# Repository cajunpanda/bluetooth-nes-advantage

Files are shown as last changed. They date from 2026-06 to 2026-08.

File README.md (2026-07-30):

# Bluetooth NES Advantage (v2)

Integrated Bluetooth for the NES Advantage (NES-026) arcade stick. It pairs directly with a
Nintendo Switch, an 8BitDo NES Retro Receiver (for a real NES), and PCs, phones, and emulators
over BLE. No case cutting and no added buttons: everything runs from the stick's own controls,
and it charges through the original cable hole.

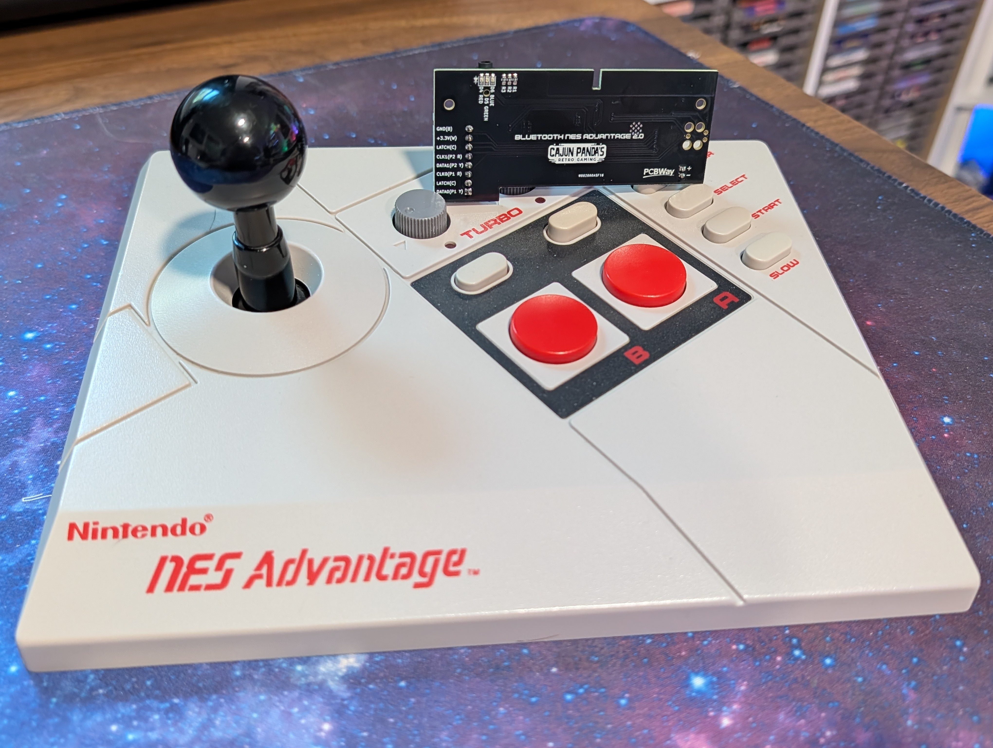
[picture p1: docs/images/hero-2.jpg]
NES Advantage with the Bluetooth board


**[Watch the overview and how-to video](https://youtu.be/xjbFiXHXB24)** for a tour of the mod and
everything below in use.

## Features

- Direct Nintendo Switch pairing (Switch Pro Controller emulation over BT Classic)
- Home, ZL + ZR (the NSO retro menu), ZL, ZR, and Capture — buttons the NES stick never had, on
  Select-held chords, instant and usable mid-game; the chord window is configurable, or off
- 8BitDo NES Retro Receiver support for playing on a real NES
- BLE gamepad mode for PC, Android, SteamOS, Linux, and BlueRetro
- Turbo and slow motion work as normal
- Player-select slider: in BLE mode the stick exposes two gamepads for take-turns play
- Wake on button press from a deep sleep that draws microamps
- Battery life on an 1800 mAh cell: about 17 hours in Switch/Receiver mode, about 37 hours in
  BLE mode, months of standby
- Low input latency: the board adds about 4 ms in Switch/Receiver mode and about 6 ms in BLE mode
- Browser-based configuration and over-the-air firmware updates, no cable needed
- RGB status LEDs, battery level monitoring, 5 V barrel jack charging
- Play while charging (load-share power path)

## Configure and update from your browser

A built-in Web Bluetooth app tests every input, tunes how the stick behaves, and flashes new
firmware over the air with no cable and nothing to install. Put the stick in config mode (hold
A + B + Select for 5 s), open the hosted
**[config page](https://cajunpanda.github.io/bluetooth-nes-advantage/)** in Chrome or Edge, and
connect. Every button, the D-pad, the player-select slider, and the turbo dials light up live as
you use them:

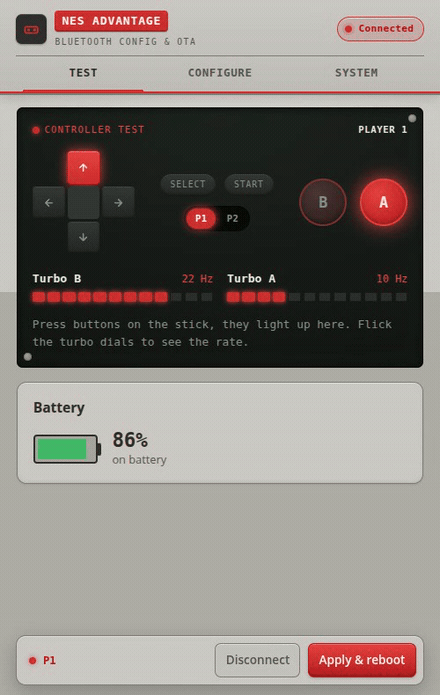
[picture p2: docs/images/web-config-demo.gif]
Live controller test in the web config page


Change transport, button profile, and directional mode and apply over the air, or drop a
`firmware.bin` on the cartridge slot to update. The
[manual](docs/MANUAL.md#configuration-and-firmware-updates) has the full walkthrough.

## How it works

A single custom PCB replaces the controller's cable. A bare ESP32-WROOM-32E reads the original
CD4021 shift registers and presents the stick as a Bluetooth gamepad in one of two modes:

- Switch mode (Bluetooth Classic): emulates a Switch Pro Controller. Pairs directly with a
  Nintendo Switch and with the 8BitDo NES Retro Receiver.
- BLE mode: a standard BLE HID gamepad ("NES Advantage") for PCs, phones, BlueRetro, and
  emulators.

Turbo, slow motion, and the player-select slider all work as originally designed.

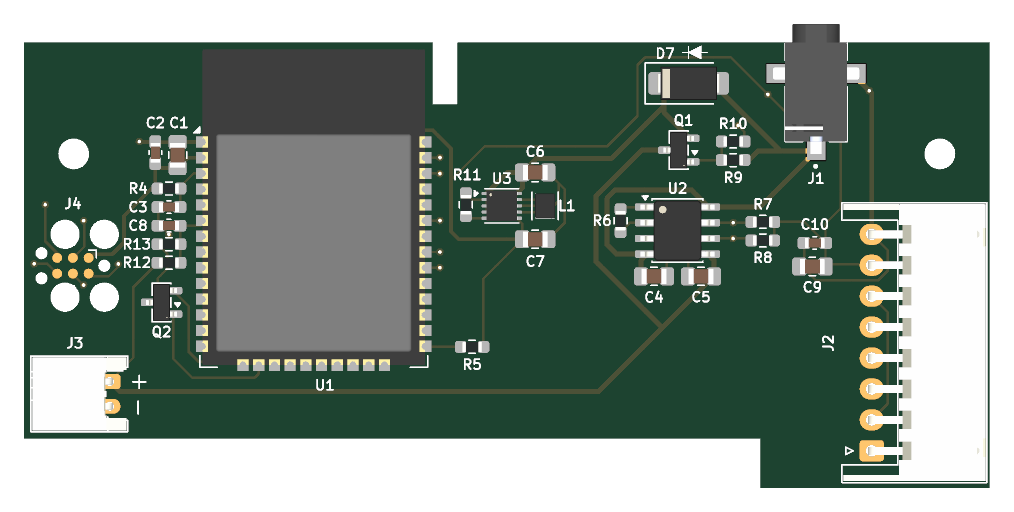
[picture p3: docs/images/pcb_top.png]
PCB top

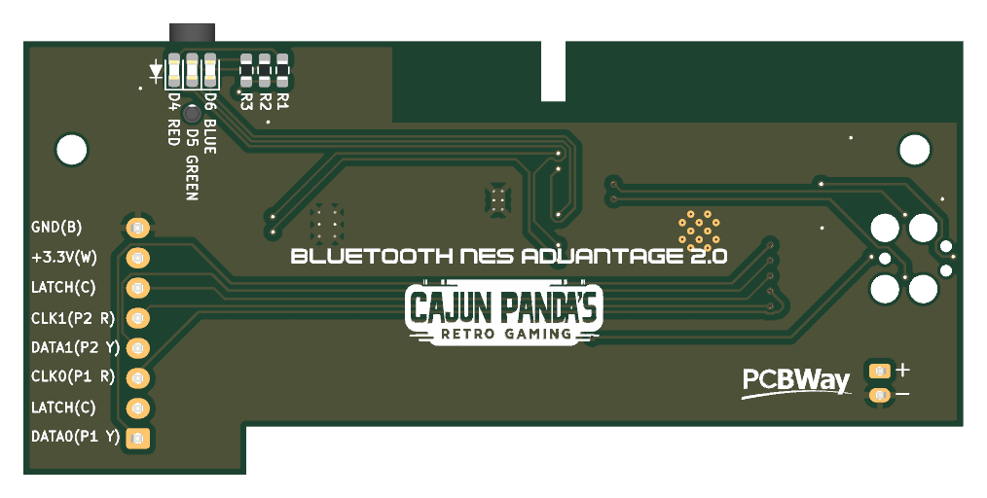
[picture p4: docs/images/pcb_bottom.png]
PCB bottom


## Documentation

Start with the guide that fits you:

- **Using a modded controller:** [docs/MANUAL.md](docs/MANUAL.md). Pairing, gestures, LEDs, button
  profiles, two-player play, charging, and firmware updates.
- **Installing the mod in your controller:** [docs/INSTALL.md](docs/INSTALL.md). Wiring the harness,
  fitting the battery and board, insulating tape, and the 3D-printed jack plug.
- **Building your own kit:** [docs/HARDWARE.md](docs/HARDWARE.md). PCB, bill of materials, board
  assembly, and connection maps.
- **Building and customizing firmware:** [docs/FIRMWARE.md](docs/FIRMWARE.md). Toolchain, module
  layout, architecture, and the config/OTA path.

## Get one prebuilt

Complete kits and assembled boards are available at
[cajunpanda.com](https://cajunpanda.com/shop/bt-nes-advantage).

## Support

Questions and help: join the [Discord](https://discord.gg/t8uT8NgTnc).

## Repository layout

| Path | Contents |
| --- | --- |
| [`firmware/`](firmware/) | ESP-IDF dual-mode Bluetooth firmware |
| [`hardware/`](hardware/) | KiCad PCB project and the 3D-printable jack plug |
| [`web/`](web/) | Web Bluetooth config and OTA update page |
| [`tools/`](tools/) | Serial monitor and build helpers |
| [`docs/`](docs/) | Manual, install guide, hardware guide, firmware guide, protocol reference |
| [`AGENTS.md`](AGENTS.md) | Working notes for contributors and AI coding agents |

## License

Licensed by medium: firmware and software under MIT, hardware (PCB and 3D models) under
CERN-OHL-P-2.0, documentation under CC-BY-4.0. See [LICENSING.md](LICENSING.md).

## PCBs

The PCBs for this product are sponsored and produced by PCBWay. As always, their service was amazing
and the fabrication as well as the shipping was fast. Because of the all-in-one customs and shipping
price, the handling of taxes and other fees was very easy.
[Click here](https://www.pcbway.com/project/shareproject/Bluetooth_NES_Advantage_865d24ef.html) to
order the PCBs from the shared project (gerbers preloaded).

## Disclaimer

This is an independent, unofficial project and is not affiliated with, endorsed by, sponsored by, or
associated with Nintendo Co., Ltd. Nintendo, NES, Nintendo Entertainment System, NES Advantage,
Nintendo Switch, and Nintendo Switch Pro Controller are trademarks of Nintendo. All trademarks are
the property of their respective owners and are used here only for identification and compatibility.
No Nintendo firmware, code, or assets are included; the Switch Pro Controller support is a clean-room
implementation of the controller's publicly documented behavior, for interoperability only.

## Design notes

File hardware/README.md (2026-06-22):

# Hardware

Open hardware for the Bluetooth NES Advantage.

| Path | Contents |
|---|---|
| [`bt-nes-advantage-pcb/`](bt-nes-advantage-pcb/) | KiCad 10 PCB project (schematic and 2-layer layout) |
| [`bt-nes-advantage-jack-plug/`](bt-nes-advantage-jack-plug/) | 3D-printable DC jack plug (STL and FreeCAD source) |

The full build reference (architecture, BOM, pin and connection maps, power path, assembly, and
layout notes) is in [`../docs/HARDWARE.md`](../docs/HARDWARE.md). Pin assignments match the firmware
(`../firmware/main/board_config.h`).

Board highlights:

- **MCU:** bare ESP32-WROOM-32E-N4 on a single 3.3 V rail (the Advantage's logic runs at 3.3 V, so
  there is no 5 V rail and no level shifting).
- **Power:** barrel jack (+5 V) to TP4056 charger, 1S LiPo, discrete load-share power path, TPS63900
  buck-boost to 3.3 V. NES LATCH/CLK/DATA sit on RTC-capable GPIOs so the ULP polls the shift
  registers in deep sleep.
- **Programming and debug:** TC2030 Tag-Connect (J4), pinned for the TC2030-FTDI-C232HD-DDHSP-0-DTR
  USB-UART cable (DTR/RTS auto-reset). No onboard USB; charging is via the barrel jack only.
- **Status:** R/G/B 0603 LEDs (active-low), visible through the transparent jack plug.
- **Board:** 2 layer, 1.6 mm, 78 x 36 mm, fits the stock case with no cutting.

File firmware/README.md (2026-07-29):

# Firmware

ESP32-WROOM-32E firmware. Native ESP-IDF v5, with two Bluetooth host stacks: BTstack for the
Classic Switch Pro Controller emulation and Bluedroid for BLE. Built with PlatformIO or plain
`idf.py`.

```bash
pio run -e wroom32 -t upload    # build and flash over the Tag-Connect cable
pio device monitor              # serial console, 115200 baud
```

The full guide (toolchain, build variants, module layout, architecture, config/OTA, and the shared
serial monitor) is in [`../docs/FIRMWARE.md`](../docs/FIRMWARE.md). The Switch Pro protocol contract
is in [`../docs/switch_pro_protocol.md`](../docs/switch_pro_protocol.md).

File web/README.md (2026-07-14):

# web: BLE configuration and OTA web app

A single-page Web Bluetooth app to test the controller, configure it, and flash new firmware
over the air. No build step, no dependencies, no external requests: one self-contained
`index.html` (inline CSS/JS). The look is a grey-and-red front-loader NES rendered as UI; see
`DESIGN.md` and `PRODUCT.md`.

## Use

1. On the controller, hold **A+B+Select for 5 s** to reboot into config/OTA mode. The
   device advertises as **"NES Advantage Config"**; the blue LED blinks while waiting and
   goes solid when connected. (On the bench you can instead enter config mode over serial
   with the `config` console command.)
2. Serve this folder from a secure context. `http://localhost` is exempt, otherwise HTTPS:
   ```bash
   cd web && python3 -m http.server 8770
   ```
   Open <http://localhost:8770/> in Chrome or Edge.
3. **Connect** and pick "NES Advantage Config". The first GATT connect on Chrome/Linux
   sometimes throws a transient `NetworkError`; the page auto-retries (a known BlueZ quirk)
   and silently reconnects if the link drops.
4. **Test:** watch every button, the D-pad, the P1/P2 select switch, and the turbo dials
   light up live, alongside a battery meter. **Configure:** change transport / button profile
   / directional mode and **Apply & reboot**. **System:** drop
   a `.bin` on the cartridge slot to flash firmware over the air, and use the device console
   (live log + the same commands as the wired UART console).

To leave config mode without a browser (the production board has no reset button): hold
**Start for about 3 s** on the controller, or wait; it returns to gameplay after 5 idle
minutes.

## Browser support

Web Bluetooth requires Chrome, Edge, or another Chromium browser. On Linux it talks to
BlueZ; if `navigator.bluetooth` is missing, enable
`chrome://flags/#enable-experimental-web-platform-features`. Safari has no Web Bluetooth; on
iPhone use a Web BLE browser such as Bluefy or BLE-Link. Firefox is unsupported.

## GATT contract

Service `5f1d0000-7c5a-4e2a-9b6e-2a8f3c9d1e00` with seven characteristics:

| UUID suffix | Name | Properties | Payload |
|---|---|---|---|
| `0001` | INFO | read + notify | JSON device info + settings |
| `0002` | CMD | write | JSON `{transport\|profile\|dirmode}` or `{action:"reboot\|forget"}` |
| `0003` | OTACTL | write + notify | OTA control opcodes / status codes |
| `0004` | OTADATA | write-no-resp | raw firmware chunks |
| `0005` | INPUT | read + notify | live controller frame (7 bytes: player, buttons, turbo A/B Hz, battery) |
| `0006` | LOG | notify | device console / log stream (UTF-8) |
| `0007` | CONSOLE | write | console command line (UTF-8); output streams back on LOG |

The firmware side is `../firmware/main/bt_config.cpp`; the two files are kept in lockstep
(UUIDs, OTA opcodes, the windowed/ACK flow control, and the INPUT frame layout). A source
build's image for OTA is `firmware/.pio/build/wroom32/firmware.bin`.
</content>

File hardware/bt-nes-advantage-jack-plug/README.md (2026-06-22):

# Jack plug

A 3D-printable plug that fills the original cable hole around the DC barrel jack. Print it in
transparent PLA so the status LEDs show through.

| File | Contents |
|---|---|
| `bt-nes-advantage-jack-plug.stl` | Print-ready mesh |
| `bt-nes-advantage-jack-plug.FCStd` | FreeCAD source |

The jack fits the CUI PJ-040 footprint in the same hole as the original NES Advantage cable. See
[`../../docs/HARDWARE.md`](../../docs/HARDWARE.md) for fit and assembly.

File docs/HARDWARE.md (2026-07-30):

# Hardware

How to build the Bluetooth NES Advantage board. You need the PCB, the components below, and a
soldering iron. Everything is hand-solderable, though the two QFN-style regulators (U2, U3) are
easiest with hot air or a hotplate. To fit a finished board into a controller, see
[INSTALL.md](INSTALL.md).

Pin assignments here match the firmware (`firmware/main/board_config.h`). The KiCad project is in
[`../hardware/`](../hardware/) and the schematic is ERC-clean.

## PCB

- Order it ready-made from the
  [PCBWay shared project](https://www.pcbway.com/project/shareproject/Bluetooth_NES_Advantage_865d24ef.html)
  (gerbers preloaded, one-click ordering).
- Or fab it yourself from the KiCad project in
  [`../hardware/bt-nes-advantage-pcb/`](../hardware/bt-nes-advantage-pcb/): standard 2-layer,
  1.6 mm, 78 x 36 mm. It fits the stock case with no cutting.

## Bill of materials

39 placed parts; R14/R15 are do-not-populate (footprint only). "HS" footprints are hand-solder
variants.

| Ref(s) | Qty | Value / MPN | Footprint | Notes |
|---|---|---|---|---|
| U1 | 1 | ESP32-WROOM-32E-N4 | RF_Module:ESP32-WROOM-32E | MCU module, 4 MB |
| U2 | 1 | TP4056-42-ESOP8 | SOIC-8-1EP (EP 2.29x3 mm) | 1S Li-ion linear charger |
| U3 | 1 | TPS63900DSKR | WSON-10-1EP (2.5x2.5 mm) | Buck-boost, 75 nA Iq |
| Q1 | 1 | AO3401A P-MOSFET | SOT-23 | Power-path battery pass |
| Q2 | 1 | 2N7002LT1G N-MOSFET | SOT-23 | Battery-sense divider ground switch |
| D4 | 1 | LTST-C193KRKT-5A (Red) | LED_0603 HS | Status LED (GPIO19) |
| D5 | 1 | LTST-C193KGKT-5A (Green) | LED_0603 HS | Status LED (GPIO21) |
| D6 | 1 | LTST-C193TBKT-5A (Blue) | LED_0603 HS | Status LED (GPIO22) |
| D7 | 1 | SS14 (Schottky, 40 V / 1 A) | Diode_SMD:D_SMA | Power-path input OR-diode |
| L1 | 1 | 2.2 uH, Isat >= 2 A, low DCR (DFE201610P-2R2M) | Inductor_SMD:L_Murata_DFE201610P | TPS63900 inductor |
| C1,C4,C5,C6,C7,C9 | 6 | 22 uF 10 V X5R (GRM21BR61A226ME44L) | C_0805 HS | IC bulk and controller decoupling |
| C2,C3,C8,C10 | 4 | 100 nF X7R (CL10B104KB8NNNC) | C_0603 HS | HF decoupling, EN delay, ADC filter |
| R1,R2,R3 | 3 | 200 ohm 5% (RC0603JR-07200RL) | R_0603 HS | LED current limit |
| R4,R5,R7,R8,R9 | 5 | 10 kohm 5% (RC0603JR-0710KL) | R_0603 HS | Pull-ups and power-path gate-up |
| R6 | 1 | 1.5 kohm 5% (RC0603JR-071K5L) | R_0603 HS | TP4056 PROG, Ichg about 780 mA |
| R10,R12,R13 | 3 | 1 Mohm 5% (RC0603JR-071ML) | R_0603 HS | Power-path gate-down and battery divider |
| R11 | 1 | 16.2 kohm 1% (RC0603FR-0716K2L) | R_0603 HS | TPS63900 CFG3, sets 3.3 V (needs +/-3% total) |
| R14,R15 | 2 | DNP | R_0603 HS | DATA pulls done by ESP32 internal pulls (see Connection maps) |
| J1 | 1 | CUI PJ-040-SMT-TR | project_footprints:CUI_PJ-040-SMT-TR | Barrel jack, +5 V charge input |
| J2 | 1 | JST S8B-XH-A(LF)(SN) | JST_XH_S8B-XH-A 1x08 | NES Advantage interface |
| J3 | 1 | JST S2B-PH-K-S(LF)(SN) | JST_PH_S2B-PH-K 1x02 | 1S LiPo battery |
| J4 | 1 | Tag-Connect TC2030-IDC | Tag-Connect_TC2030-IDC-FP 2x03 | UART program/debug, needs no part |

## Accessories and tools

- **Battery:** [103450 3.7 V LiPo](https://a.co/d/7UFYwX9), 1500 to 2000 mAh with a JST-PH plug.
  Check polarity before connecting; there is no standard.
- **J2 wiring harness:** [8-pin JST-XH harness cable](https://a.co/d/abYfjqw).
- **Charging cable:** [5 V DC barrel jack cable (2.5 x 0.7 mm)](https://a.co/d/4bPUQj2).
- **Programming cable (self-built boards only):** Tag-Connect
  [TC2030-FTDI-C232HD-DDHSP-0-DTR](https://www.tag-connect.com/product/tc2030-ftdi-c232hd-ddhsp-0-dtr)
  (USB to TC2030 serial, 3.3 V, with DTR for auto-reset). The legged version clips into the board;
  the no-legs version works with the
  [TC2030-CLIP](https://www.tag-connect.com/product/tc2030-retaining-clip-board-3-pack). Only
  needed to put the first firmware on a blank board. Kit boards come pre-flashed, and all updates
  after that happen over the air from the browser.

## Build the board

1. Solder the SMD parts: resistors and capacitors first, then D7 and the LEDs (watch polarity), then
   U2 and U3 (exposed pads, hot air or hotplate recommended), then L1, Q1, Q2, and the ESP32 module.
   Finish with J1, J2, and J3.
2. Flash the firmware before installing, so you can verify the board on the bench. See
   [FIRMWARE.md](FIRMWARE.md) for the first flash over the Tag-Connect cable.

Once the board is built and flashed, install it into the controller: see [INSTALL.md](INSTALL.md).

## Connection maps

### ESP32-WROOM-32E (U1)

| GPIO | Net | Connects to | Notes |
|---|---|---|---|
| GPIO25 | LATCH | J2 (4021 latch) | RTC out (ULP drives in sleep) |
| GPIO26 | CLOCK_0 | J2 (CLK P1) | RTC out |
| GPIO27 | CLOCK_1 | J2 (CLK P2) | RTC out |
| GPIO32 | DATA_0 | J2 (data P1); R14 DNP | RTC in, ESP32 internal pull |
| GPIO33 | DATA_1 | J2 (data P2); R15 DNP | RTC in, ESP32 internal pull |
| GPIO34 | BATT_SENSE | R12/R13 divider mid; C8 filter | ADC1_CH6, input-only |
| GPIO13 | BATT_EN | Q2 gate | enables divider only while sampling |
| GPIO19 | LED-R | +3.3V to R1 to D4 to GPIO19 | active-low |
| GPIO21 | LED-G | +3.3V to R2 to D5 to GPIO21 | active-low |
| GPIO22 | LED-B | +3.3V to R3 to D6 to GPIO22 | active-low |
| GPIO23 (2.0) / GPIO4 (2.1) | CHG_STAT | TP4056 CHRG; R7 pull-up | open-drain status in |
| GPIO18 | STBY_STAT | TP4056 STDBY; R8 pull-up | open-drain status in |
| GPIO1 (U0TXD) | UART_TX | J4 pin 3 | to cable RXD |
| GPIO3 (U0RXD) | UART_RX | J4 pin 4 | from cable TXD |
| EN | EN | J4 pin 6; R4 pull-up + C3 | reset; from cable RTS |
| GPIO0 | BOOT | J4 pin 2; R5 pull-up | boot/download strap; from cable DTR |
| 3V3 | +3.3V | U3 VOUT; C1/C2 at module | |
| GND | GND | plane; incl. module thermal pad | |

Module power decoupling: C1 (22 uF) + C2 (100 nF) at the 3V3 pin. GPIO12 (MTDI strap) must never be
driven. The DATA lines use the ESP32 internal pulls (opposite polarity awake vs asleep), so R14/R15
stay DNP.

CHG_STAT is the one pin that differs between board revisions. PCB 2.0 puts it on GPIO23, which is
not RTC-capable, so a sleeping stick cannot notice a charger being plugged in and shows nothing
until something else wakes it. PCB 2.1 moves it to GPIO4 (RTC), so an ext1 wake lights the charge
LED on insert. One firmware build covers both: it probes the two candidate pins at boot and uses
whichever one R7 actually pulls up, so no build flag or board-ID pin is needed.

### TP4056 charger (U2)

| Pin | Name | Net / connection |
|---|---|---|
| 1 | TEMP | GND (thermistor sensing disabled) |
| 2 | PROG | R6 (1.5 kohm) to GND, Ichg about 780 mA |
| 3 | GND | GND (+ EPAD) |
| 4 | VCC (VIN) | +5V; C4 (22 uF) decouple. VIN range 4 to 8 V |
| 5 | BAT | +BATT; C5 (22 uF) decouple |
| 6 | STDBY | STBY_STAT to U1 GPIO18; R8 pull-up to +3.3V |
| 7 | CHRG | CHG_STAT to U1 GPIO23 (PCB 2.0) or GPIO4 (PCB 2.1); R7 pull-up to +3.3V |
| 8 | CE | +5V (charger enable) |
| EP | EPAD | GND |

### TPS63900 regulator (U3)

| Pin | Name | Net / connection |
|---|---|---|
| 1 | EN | Vsys (always-on; rail must stay up for the ULP) |
| 2 | SEL | GND (selects VO(1), the fixed setpoint) |
| 3 | CFG1 | GND |
| 4 | CFG2 | GND (unlimited input-current limit) |
| 5 | CFG3 | R11 (16.2 kohm 1%) to GND, sets 3.3 V |
| 6 | VOUT | +3.3V; C7 (22 uF) |
| 7 | LX2 | L1 |
| 8 | GND | GND |
| 9 | LX1 | L1 |
| 10 | VIN | Vsys; C6 (22 uF) |
| 11 | GND (EP) | GND |

### Connectors

- **J1 barrel jack:** +5V, GND. Aligned to the Advantage's existing cable hole.
- **J2 NES Advantage (8-pin JST-XH):** 1 DATA_0, 2 LATCH, 3 CLOCK_0, 4 DATA_1, 5 CLOCK_1, 6 LATCH,
  7 +3.3V, 8 GND. Pins 1 to 3 are the P1 4021 bundle, 4 to 6 the P2 bundle; the shared latch line
  gets one conductor per shift register (pins 2 and 6 are the same net). Decouple +3.3V/GND right
  here with C9 (22 uF) + C10 (100 nF).
- **J3 battery (2-pin JST-PH):** +BATT, GND.
- **J4 TC2030 (6-pin):** 1 +3.3V, 2 BOOT (GPIO0), 3 UART_TX (GPIO1), 4 UART_RX (GPIO3), 5 GND,
  6 EN. Matches the TC2030-FTDI-C232HD-DDHSP-0-DTR cable pin-for-pin (1 VCC, 2 DTR, 3 RXD, 4 TXD,
  5 GND, 6 RTS): DTR drives BOOT and RTS drives EN for esptool auto-reset, and the cable's
  regulated 3.3 V / 250 mA VCC shares the rail (or the board runs on battery). The legged footprint
  also takes the no-legs cable plus a TC2030-CLIP.

### Power nets

- `+5V`: J1 to TP4056 VCC/CE (C4) and power-path input (D7 anode).
- `+BATT`: cell (J3) to TP4056 BAT (C5), power-path Q1 drain, and battery divider (R12).
- `Vsys`: power-path output to TPS63900 VIN/EN (C6).
- `+3.3V`: TPS63900 VOUT (C7) to U1, J2, pull-ups, LEDs.

## Layout notes

- **Antenna keepout:** no copper or parts under or beside the WROOM antenna; point it off the board
  edge.
- **Module decoupling:** C1 + C2 right at U1's 3V3 pin; short wide trace; stitch the module pad to
  GND with vias.
- **Controller decoupling:** C9 + C10 at J2, with low-impedance +3.3V/GND pours. Do not skip this.
- **Buck-boost:** tight C6-L1-C7-PGND loop, small switch node, CFG resistors close to the pins;
  keep R11 at 1% / 200 ppm.
- **Charger thermal:** TP4056 pad to generous GND copper (about 1 W at high charge); keep it away
  from the cell and antenna.
- **ADC:** keep R12/R13/C8 and the GPIO34 trace short and away from the switch node; ADC1 only.
- **RTC pins:** LATCH/CLK/DATA (25/26/27/32/33) bit-bang the 4021 from the ULP in deep sleep, so
  route them cleanly with no series parts in the path.
- **Test points:** +BATT, Vsys, +3.3V, GND for bring-up and standby-current measurement.

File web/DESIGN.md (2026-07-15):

# Design

A control panel that looks like the machine it configures: a grey front-loader
NES rendered as UI. One self-contained `index.html` (no build, no external
assets). Committed color strategy: two-tone **molded grey plastic** carries the
surface, a single **NES red** carries every active state and primary action, and
a dark **CRT screen** inset holds the live readouts (the button tester, the
turbo meters, the device log).

## Theme

- Light molded-grey plastic body with dark screen insets. **Committed** strategy
  (the grey plastic surface and the red accent carry the identity), not the
  restrained-neutral product default. Chosen because the brief is diegetic: the
  page should *be* an NES, so the enclosure is the design, not a backdrop behind
  it.
- Scene sentence: a builder at a lit workbench, stick in hand, wants the panel to
  read like the console's own front face, hard-edged injection-molded plastic,
  not a soft web card.
- Not the cream/paper trap: the light surface is a true cool-warm **grey** (not a
  warm near-white), and it is sold as plastic by molded detailing (raised/inset
  edges, panel seams, the red two-tone stripe, sparing screw-heads), never as a
  paper page.

## Color (OKLCH)

**Molded grey plastic** (the console body, the hero surface):

- `--plastic` 0.83 0.008 95 (front panel) · `--plastic-2` 0.74 0.010 95 (lower
  two-tone / recessed wells) · `--plastic-hi` 0.90 0.006 95 (top highlight edge)
  · `--plastic-lo` 0.58 0.012 95 (molded seam / bottom shadow)
- `--bezel` 0.30 0.006 250 (the near-black controller/bezel graphite)

**CRT screen** (dark readout insets, faint green phosphor cast):

- `--screen` 0.19 0.006 150 · `--screen-2` 0.25 0.008 150 · `--screen-line`
  0.33 0.010 150

**NES red** (the one hot accent: primary actions, pressed buttons, current
selection, the two-tone stripe):

- `--red` 0.55 0.19 27 · `--red-2` 0.49 0.19 27 (hover/active) · `--red-ink`
  0.98 0.02 27 (near-white on a red fill) · `--red-soft` (16% red, glow/tints)

**Ink:**

- On plastic: `--ink` 0.30 0.010 95 · `--muted` 0.46 0.010 95 (both clear 4.5:1
  on `--plastic`/`--plastic-2`)
- On screen: `--ink-screen` 0.92 0.02 150 · `--muted-screen` 0.64 0.02 150

**Semantic** (battery, status): `--ok` 0.70 0.16 150 · `--warn` 0.78 0.15 80 ·
`--danger` reuses `--red`. Pressed controller buttons and the turbo meter glow
red (echoing the real red A/B buttons), so red doubles as the "live" color.

Contrast: dark ink on light grey for all body/labels; near-white on red fills and
on the dark screen; the red accent only appears at large-text / UI weights where
it clears 3:1.

## Typography

One family plus a mono, on a **screen-vs-panel** split (product register: no
display font, no pixel font, the retro is carried by color and molding):

- `--font-sans` = `system-ui` stack: headings, control labels, prose, buttons.
- `--font-mono` = `ui-monospace` stack: the wordmark, every numeric readout (%,
  Hz, mV), the device log and console, the P1/P2 chip, equipment micro-labels.
- Fixed rem scale, tight ratio (~1.15), product register. No `clamp()` display
  sizes. Wordmark is a letter-spaced bold sans set in a red stripe (an NES
  title-bar nod), never a pixel typeface.

Micro-labels (`.label-mono`): mono, uppercase, 0.12em tracking, `--muted`. These
are diegetic equipment labeling (`PLAYER`, `TURBO A`, `POWER`), deliberately not
the tracked-uppercase marketing eyebrow, they sit on controls, not above every
section.

## Layout: front-panel console

- Content max-width ~46rem. Breakpoint at **820px**, same skeleton as the sibling
  GameBoy HiFi panel (rail + main, `display: contents` dissolve on mobile).
- **Desktop (>= 820px):** two-pane. A ~15rem left **control deck** (wordmark on
  the red stripe, vertical Test / Configure / System nav, connection pill, pinned
  footer with the player chip + Disconnect + Apply). Beside it a scrolling
  **main** surface led by the button tester.
- **Mobile (< 820px):** the deck dissolves; its top block becomes a sticky top
  bar (wordmark + status pill + underline tabs), its footer a fixed bottom action
  bar.

## Components

- **Button tester (hero):** a dark CRT-screen panel holding a schematic NES
  Advantage: D-pad cross, oval Select/Start, two large red A/B circles, and the
  Turbo A/B dials. Each element lights red the instant its button is pressed
  (`box-shadow` glow + fill), driven by the live INPUT notify. This is the thing
  a builder came to see; it never lies about hardware state and updates even
  under `prefers-reduced-motion`.
- **P1/P2 switch:** a molded slide switch on the tester showing which player the
  Advantage's physical select switch reports, with the player number in mono. It
  reflects hardware, it is not a user toggle.
- **Turbo meters:** two horizontal segmented LED bars (A, B) on the screen, lit
  red proportional to the measured turbo firing rate, with a mono `Hz` readout.
- **Battery gauge:** a molded cell outline that fills green/amber/red by state of
  charge, with `%` and a charge glyph; reads "absent" cleanly when no cell.
- **Molded panels:** light-grey surfaces with a raised top edge + inset bottom
  shadow so they read injection-molded; sparing corner screw-heads (never on
  every panel). Sentence-case titles, no eyebrows.
- **Red slide actions:** the primary action (Connect, Apply) is a red slide
  styled after the NES POWER switch; secondary actions are ghost buttons with a
  hairline plastic border.
- **Selects / sliders / file drop:** native controls restyled to the plastic
  vocabulary; the OTA drop zone is a "cartridge slot" ("insert firmware .bin").
- **Device console:** dark screen, mono green-cast text, a command line that
  streams the same log as the wired UART console.
- **Status pill / player chip:** mono; red when connected, muted when not.

## Motion

- 150-220 ms, state-conveying only. A short power-on reveal plays once on connect;
  section switches crossfade via View Transitions. Button-tester lights are
  immediate (no easing lag on hardware feedback).
- `prefers-reduced-motion`: entrance + view transitions collapse to instant; the
  live tester and meters keep updating (they are state, not decoration).

## Constraints

- Single self-contained `index.html`; inline CSS/JS; no build step, no external
  requests (CSP-safe, offline, forkable). Served over localhost/HTTPS for Web
  Bluetooth's secure-context requirement.
- Web Bluetooth only (Chrome/Edge desktop/Android). All state comes from the BLE
  config server; the GATT contract is duplicated by design in
  `firmware/main/bt_config.cpp` and this page and must stay in lockstep.
</content>

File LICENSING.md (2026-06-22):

# Licensing

This is an open hardware and firmware project, so different parts are released
under licenses appropriate to their medium. Each directory below carries its own
`LICENSE` file with the full text; this page is the map.

| Path | Contents | License |
|---|---|---|
| `firmware/` | ESP-IDF firmware | **MIT** ([`LICENSE`](LICENSE)) |
| `web/` | BLE config and OTA web app | **MIT** ([`LICENSE`](LICENSE)) |
| `tools/` | Host-side Python utilities | **MIT** ([`LICENSE`](LICENSE)) |
| `hardware/` | KiCad PCB project, schematic, layout, footprints, 3D models | **CERN-OHL-P-2.0** ([`hardware/LICENSE`](hardware/LICENSE)) |
| `docs/` | Design docs, schematics, protocol notes | **CC-BY-4.0** ([`docs/LICENSE`](docs/LICENSE)) |

SPDX: `MIT`, `CERN-OHL-P-2.0`, `CC-BY-4.0`. Source files carry an
`SPDX-License-Identifier` header so the per-file license is machine-readable.

## Third-party material

- `firmware/components/cjson/` is cJSON by Dave Gamble and contributors,
  **MIT** licensed. It is vendored unmodified and retains its own terms in the
  file headers.

## Why the split

Software licenses are written around copyright over source code and do not map
cleanly onto hardware design files. CERN-OHL-P-2.0 is purpose-built for hardware
and is the permissive member of the CERN-OHL family. CC-BY-4.0 is the
conventional choice for documentation.

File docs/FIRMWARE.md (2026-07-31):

# Firmware

ESP32-WROOM-32E firmware. Native ESP-IDF v5, with two Bluetooth host stacks: BTstack for the
Classic Switch Pro Controller emulation and Bluedroid for BLE (see
[Two Bluetooth host stacks](#two-bluetooth-host-stacks)). Built with PlatformIO or plain
`idf.py`. Source is in [`../firmware/`](../firmware/).

## Building from source

Requirements: Python 3 and [PlatformIO](https://platformio.org/) (CLI or the VSCode extension). Flash
and monitor through **[benchmux](https://github.com/cajunpanda/benchmux)** (see the next section);
these docs use it for every flash and serial example.

```bash
cd firmware
pio run -e wroom32     # build (plain ESP-IDF works too: idf.py set-target esp32 && idf.py build)
```

A build is the main static check; there is no unit-test suite. Treat warnings in `main/*.cpp` as
regressions. If the board already runs firmware, skip the cable and flash your build's
`firmware/.pio/build/wroom32/firmware.bin` over the air from the config page (drop it on the OTA
card; the stick verifies and reboots into it). See [`../web/README.md`](../web/README.md).

## Serial monitor and flashing (benchmux)

Only one process can own the serial port, which is awkward when a person and an automated tool both
want to watch it. **[benchmux](https://github.com/cajunpanda/benchmux)** (`serial_proxy.py`) owns the
port and tees everything to a shared logfile, and its `flash` command coordinates the port handoff so
the monitor never has to be stopped by hand. It is the recommended way to flash and monitor this
board. Run it by path or symlink it onto `PATH`:

```bash
serial_proxy.py monitor --port /dev/ttyUSB0                       # own the port, tee to /tmp/serial_proxy.log
tail -f /tmp/serial_proxy.log                                     # watch live, any number of readers
serial_proxy.py flash --flash-cmd 'pio run -e wroom32 -t upload'  # build + upload without stopping the monitor
```

`pio device monitor` needs a real TTY; reading the proxy's logfile is the scriptable path. `ble_proxy.py`
does the same over BLE (console + OTA) with no cable. See [`../tools/README.md`](../tools/README.md).

## First flash (blank board)

A freshly fabbed board has no firmware, so the first flash goes over the Tag-Connect serial cable
(see [HARDWARE.md](HARDWARE.md)); after it, all updates are over the air. Install esptool
(`pip install esptool`), press the cable onto the J4 pads (it powers the board and auto-resets, no
buttons), then flash the merged image through benchmux:

```bash
serial_proxy.py monitor --port /dev/ttyUSB0
serial_proxy.py flash --flash-cmd 'esptool.py --chip esp32 --baud 460800 write_flash 0x0 bt-nes-advantage.bin'
```

The blue LED blinks on boot (pairing mode). To flash the separate images instead of the merged
`bt-nes-advantage.bin`, pass them to the same `write_flash`: `0x1000 bootloader.bin 0x8000
partitions.bin 0xf000 ota_data_initial.bin 0x20000 firmware.bin`.

### The merged image erases settings and pairings; the separate images do not

`nvs` lives at `0x9000..0xF000`, between the partition table and `otadata`, and holds bonds,
transport, button profile, directional mode, and the identity generation. A raw merged image is one
contiguous blob from `0x0`, so `write_flash 0x0 bt-nes-advantage.bin` pads that hole with `0xFF` and
takes NVS with it. The four separate images skip the hole and leave NVS intact, which is why the
benchmux flash command above uses them.

Both paths are supported and each has its own rule:

- **Updating an existing controller** is the common case, and it **must never erase NVS** unless the
  release genuinely breaks the NVS schema. This is the OTA image (`firmware-vX.Y.Z.bin`) via the
  config page, which only writes the inactive app slot. Over serial, use the four separate images.
  On a real schema break, erasing is the point: do it deliberately and say so in the release notes.
- **Flashing a blank or bricked board** is the merged image (`bt-nes-advantage-vX.Y.Z.bin`) at `0x0`.
  Erasing NVS here is correct and wanted: there is nothing to preserve, and it is the recovery path
  for corrupt NVS. Label it as such in the release notes so nobody reaches for it to update.

If a merged image ever needs to preserve NVS, build it with `esptool.py merge_bin --format hex`:
Intel HEX keeps the gap instead of padding it.

## Module layout (`main/`)

| File | Role |
|---|---|
| `app_main.cpp` | Entry point and state machine: gestures, sleep, LEDs, player select |
| `nes_controller.{hpp,cpp}` | CD4021 read and player-select |
| `settings.{hpp,cpp}` | NVS settings: transport, profile, directional mode, identity generation |
| `bt_transport.{hpp,cpp}` | Transport-neutral `bt::` API, dispatch to the active transport |
| `bt_pro_btstack.cpp` | BT Classic Switch Pro transport (BTstack) and connection state machine |
| `bt_ble.cpp` | BLE HID transport, two HID services (P1/P2) for take-turns play |
| `bt_config.{hpp,cpp}` | BLE config/OTA boot mode: GATT settings service plus `esp_ota` update |
| `linklog.{hpp,cpp}` | Always-on black box for pairing/reconnect events (see [Link log](#link-log)) |
| `power.{hpp,cpp}` | ULP sleep polling, deep-sleep entry, post-wake RTC-GPIO release |
| `battery.{hpp,cpp}` | Battery monitor (ADC divider plus TP4056 status) |
| `board_config.h` | Pin map for the production board (matches [HARDWARE.md](HARDWARE.md)) |
| `board.{hpp,cpp}` | Board revision probe: resolves the CHG_STAT pin, which moved on PCB 2.1 |

`partitions.csv` defines two 1.75 MB OTA app slots plus `otadata`, so config mode can update
firmware over the air. `sdkconfig.defaults` holds the project Kconfig; key names can drift between
IDF versions, so reconcile with `menuconfig` if you change IDF.

## Two Bluetooth host stacks

One controller, two hosts, one of each per boot - selected by the transport setting:

- **Classic (Switch Pro)** runs on **BTstack**, vendored in `firmware/components/btstack`
  (see its README for the pinned version, what is vendored, and the license). BTstack ships a real
  HID *device* profile, so the Pro emulation is plain library calls; the same thing on Bluedroid
  needed five build-time patches to its own source to bend the inbound HID path, Class-of-Device
  handling, and Secure Connections support into shape. Moving to BTstack deleted all five and
  dropped ~80 KB of flash.
- **BLE** (gameplay transport and the config/OTA boot mode) stays on **Bluedroid**.

Bluedroid's Classic half is therefore compiled out (`CONFIG_BT_CLASSIC_ENABLED=n`), which also
removes a `sdp_init` symbol clash with BTstack. Earlier builds carried five
`tools/patch_bluedroid_*.py` pre-build patches to bend Bluedroid's Classic HID into shape; they
are gone with it (recoverable from git history before the BTstack switch, if ever needed).

## Architecture

Gestures (hold-combos) are matched in `detect_gesture()` in `app_main.cpp`; the user-facing list is
in [MANUAL.md](MANUAL.md).

Chords (Select as a shift key) are resolved by `apply_chords()` in `app_main.cpp`, one layer below
the gestures and above the transports. It synthesises the four buttons the NES stick has no way to
send (Home, Capture, ZL, ZR) into `bt::NesInput` and clears the NES buttons it consumed, so a
transport maps them like any other input and needs no chord awareness. Three consequences worth
knowing before touching that code:

- **Minus cannot be sent on press.** HID has no undo: once `minus=1` is on the wire the host has
  acted on it, and sending `minus=0` when the chord arrives doesn't un-open the menu it just opened.
  So Minus is withheld until the outcome is known: a chord forms (Minus never sent), or the window
  closes without one (Minus commits and follows the hold from there).
- **The window is a setting, not a constant.** `settings::chord_window_ms(transport)` is read once
  at boot into `s_chord_window`. `kChordOff` disables the layer entirely and `apply_chords()` returns
  immediately, so Select is an ordinary button; `kChordHold` never closes the window, which is the
  2.2.x behaviour (chords at leisure, Select never holdable); anything else bounds it in ms. Classic
  defaults to 200 ms. **BLE is hard off**, not merely defaulted off: the chord outputs would land on
  buttons 5-8 that no profile reads, so `chord_window_ms()` returns `kChordOff` for BLE without
  consulting NVS and `set_chord_window_ms()` drops the write. The config service and the web page
  refuse to offer it there for the same reason, so no surface can promise what the device ignores.
- **The poll loop gates sends on the resolved snapshot, not `stateChanged()`.** The chord layer
  breaks the 1:1 between raw and reported state in both directions: the Minus pulse ends on a timer
  with no button moving, and a chord changes what a held button means without the raw state moving.

The commit that closes the window is gated on `s_chord_fired` alone, not on whether a member is
currently down. A chord formed *inside* the window keeps the shift for as long as it's held; a member
arriving *after* the deadline must not resurrect the chord, which is the whole point of bounding it.

This layer has host-side tests: `./tests/run.sh` compiles the chord section out of `app_main.cpp`
against a fake clock and runs the window modes and edge cases. Run it after touching `apply_chords()`;
the timing edges are hard to reproduce by hand on a console. The extraction keys on the section's
banner comments, so renaming them means updating `tests/run.sh` too.

### Sleep and wake

The NES buttons sit behind CD4021 shift registers, so wake-on-button cannot be a plain GPIO
interrupt; button state is only visible by clocking the register. In deep sleep the ULP coprocessor
pulses LATCH/CLK on RTC GPIOs, shifts in both players' 8 bits, compares against the stored state,
and wakes the main core only on a change. The CPU and radio are fully off between polls. Wake
latency is roughly 30 ms; standby draw is in the microamp range. The firmware wakes fully only if
Start is held; any other button change goes back to sleep.

Pin constraints that follow:

- LATCH/CLK/DATA must be RTC-capable GPIOs. LATCH/CLK use RTC output pins (25/26/27); DATA stays on
  32/33, which have internal pulls (GPIO 34 to 39 are input-only without pulls).
- Battery sense must be ADC1 (GPIO 32 to 39); ADC2 is unusable while the radio is on.
- The DATA pull direction differs by phase (pull-down awake for the player-select sentinel, pull-up
  asleep for standby current), so the pulls are the ESP32 internal ones and the external pull
  footprints (R14/R15) stay unpopulated.
- GPIO12 (MTDI strap) must never be driven.

The pin map is in [`../firmware/main/board_config.h`](../firmware/main/board_config.h) and matches
[HARDWARE.md](HARDWARE.md).

### Transports

- **One radio per boot.** The active transport (Classic or BLE) is an NVS setting; only that
  identity advertises. The Select+Start gesture toggles it and reboots. The two identities (Pro
  Controller vs NES Advantage) are never live at once.
- **Forget rotates the identity.** The hold-Select gesture clears all bonds, XORs the base MAC with
  a persisted generation counter, and reboots. The device returns with a fresh BT address, so a
  forgotten host cannot half-reconnect against stale pairing state.
- **Reconnect vs fresh pair.** Classic stays passive and lets the host open the HID channels; it
  does not device-initiate, even with a stored bond. BLE advertises for the host to connect.

### Link log

`linklog.cpp` records why a link did or did not come up. It records always rather than on a switch:
a failed reconnect happens at power-on, before anything could be armed, and the gesture that reads
it out reboots the device. Storage is chosen to survive that reboot.

- **RTC ring** (96 events, `RTC_NOINIT_ATTR`): the fine-grained trace. Survives `esp_restart` and
  deep sleep, the two transitions that matter, but not a battery pull. Events span boots, so the
  dump prints a `---- boot ----` separator where the timestamps restart.
- **NVS summary** (8 boots, namespace `linklog`): one 20-byte record per boot, for the power-off
  case. Written at outcomes only: HID up, HID gone, pages exhausted, deep sleep, and immediately
  before the reboot into config mode, which is the boot being asked about. Capped at 8 writes per
  boot, because this partition also holds the BTstack link keys.
- **What it captures, reconnect side:** stored bonds at boot, each page attempt and its status,
  ACL, authentication and encryption status, whether the host asked for our link key, whether it
  stored a new one (it had forgotten the bond and re-paired), HID open and close, and the
  disconnect reason.
- **What it captures, pairing side:** the host's page including its class of device, the role
  change, its IO capability response with authentication requirements and OOB flag, numeric
  confirmation, any passkey or OOB request, a legacy PIN request, and the simple-pairing status.
  That is what identifies an unknown host and says which half of the handshake refused. This
  device is NoInputNoOutput with no display and no spare keys, so a passkey or OOB request cannot
  be answered at all; a host requiring MITM either degrades to Just Works or refuses, and only the
  SSP status says which; a host requesting no bonding keeps no key, so every session starts by
  pairing again.
- **What it captures on BLE:** stored bonds at boot, whether advertising actually started, the HID
  connect, which keys the host distributed (a peer LTK is the bond, and without one the link is
  encrypted for this session only), the authentication result with Bluedroid's failure reason, the
  granted connection parameters, and the disconnect reason. The passkey, numeric-comparison and
  OOB requests are recorded but not answered: this device sets `ESP_IO_CAP_NONE`, so a host asking
  for any of them wants input that does not exist here, and the unanswered request is the finding.
  Both transports share the bond count, disconnect reason and those input-request codes; the rest
  differ, so the per-boot summary prints a `classic` or `ble` column set rather than one layout
  that is half zeroes either way.
- **Readout:** the `dbg` console command, on the wire or over BLE. Over BLE the config loop paces
  the dump a few lines per drain instead of printing it from the command dispatch, which runs on
  the BT task and would overrun the 3 KB log ring. The config page's **save link log** button runs
  `dbg`, captures the stream to its footer, and downloads it as a text file.

### Config / OTA mode

A+B+Select reboots into a dedicated BLE-only mode (`bt_config.cpp`) serving a small custom GATT
service, so a browser can change settings, test the controller live, and flash firmware over the
air. The web client is the single-file [`../web/index.html`](../web/index.html). The GATT contract
(service `5f1d0000-...`, seven characteristics: INFO/CMD/OTACTL/OTADATA plus INPUT/LOG/CONSOLE) is
documented at the top of `bt_config.cpp` and mirrored in `web/index.html`; change them together.

- Entry is a one-shot flag in `RTC_NOINIT_ATTR` memory, honored only when the reset reason is a
  software reset. Any cold boot returns to gameplay. The `config` bench-console command arms the
  same flag over serial, so config mode can be entered without the button gesture.
- Boot also enters config mode when no controller is detected. A disconnected NES Advantage reads as
  all-buttons-held (both CD4021 data lines idle-high), which would oscillate player-select and trip
  the Select+Start transport gesture into a reboot loop. `NESController::diagnose()` catches this at
  boot; config mode reports it as `wiring` in the INFO JSON (none/p1/p2/both), blinks the red LED,
  and answers the `diag` console command. The `diag` command works in gameplay too.
- Config mode brings up the battery monitor and streams a live INPUT frame (buttons, player-select,
  turbo rate) plus the device log (LOG), and takes console commands (CONSOLE) whose output it
  echoes back over LOG.
- Config mode advertises on a distinct BT address (factory MAC with one byte flipped). Hosts cache
  GATT layouts per address; without this, a host that had bonded the gameplay HID would reuse the
  stale handle map and fail to connect.
- The production board has no accessible reset button, so every exit is firmware driven: hold Start
  3 s, a 5-minute idle timeout, and an OTA stall watchdog.
- OTA is the standard `esp_ota` dual-slot scheme. Images are SHA-256 verified before the boot
  partition switches; a bad upload leaves the running slot untouched.

### Input latency

| Term | Approach |
|---|---|
| Sample | 1 kHz tick, 2 ms poll loop (~2.4 ms real period): about 1.2 ms average press-to-latch |
| Read | 4021 latch plus 8-bit shift-out: about 0.4 ms at the default 80 MHz |
| Hand-off | Reports ship on input change (task notify), not on a timer tick: tens of us |
| Air, BLE | Interval pinned at 7.5 ms (the BLE floor on this silicon): 3.75 ms average wait |
| Air, Classic | QoS requests t_poll about 10 ms to pin the link active; typical wait a few ms |

Board-side total, press to radio hand-off, is roughly 6 ms average on BLE and 4 ms on Classic — both
inside a single 16.7 ms frame, and small against the host stack and display downstream. Pinning the
BLE interval at 7.5 ms roughly halves worst-case report wait versus a host-chosen 15 ms. BLE's
retransmit granularity is a whole interval (+7.5 ms) where Classic retries a slot at a time
(+1.25 ms), so Classic has both the better average and the gentler jitter tail.

The Classic figure is the softer of the two: the QoS t_poll pin does not actually guarantee the link
stays out of sniff. A real Switch was observed holding the link in sniff steady state regardless (see
`../history/power-tuning/README.md`), which would put Classic latency under the negotiated sniff
interval rather than t_poll. That interval has not been measured.

### Player select and two-player

The BLE transport registers the same report map twice (two HID services with distinct report IDs),
so hosts enumerate two gamepads and the player-select slider routes the stick to P1's or P2's report
for take-turns play. Classic is one Pro Controller (one player); the slider only picks which. The
host-by-host behavior is in [MANUAL.md](MANUAL.md).

## Protocol reference

The byte-level Switch Pro Controller emulation contract (identity, input/output reports, handshake
order, sniff and connection-direction behavior) is in
[`switch_pro_protocol.md`](switch_pro_protocol.md).

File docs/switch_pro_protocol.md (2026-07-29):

# Switch Pro Controller: BT Classic emulation reference

Protocol reference for the Switch Pro Controller emulation in
[`../firmware/main/bt_pro_btstack.cpp`](../firmware/main/bt_pro_btstack.cpp) (BTstack; see
[FIRMWARE.md](FIRMWARE.md) "Two Bluetooth host stacks"). It covers the identity, input and
output reports, the handshake, and the two link-layer behaviors the emulation depends on.

## Identification

The Switch does not validate the SDP HID report descriptor. It identifies the controller by
VID/PID `0x057E`/`0x2009`, device name `"Pro Controller"`, and Class of Device, then negotiates
everything over the `0x01` and `0x21` subcommand handshake on the L2CAP interrupt channel. Get the
identity right, answer the subcommands, and stream `0x30`. The descriptor still declares report IDs
0x30/0x21/0x01/0x10 so the local HID layer can route reports by ID.

| Field | Value |
|---|---|
| VID / PID | `0x057E` / `0x2009` |
| Device name | `"Pro Controller"` (exact) |
| Class of Device | major `0x05` (Peripheral), minor gamepad, CoD `0x002508` |
| HID SDP subclass | `0x08` (gamepad) |
| Channels | L2CAP control PSM `0x11`, interrupt PSM `0x13` |

Publish VID/PID via the SDP DI record, set the name and CoD, and be Connectable and Discoverable.

### The CoD is a hard discovery gate on the Switch 2 (and the ordering matters)

`0x002508` is not cosmetic. On the **Switch 2**, the Change Grip/Order inquiry pages a device **only
if its CoD is exactly a real Pro's `0x002508`**, which includes the *Limited Discoverable* service
class bit `0x2000`. Get this wrong and the console never even pages you; there is nothing to debug
further up the stack. Proven by A/B against the console: a host advertising `0x002508` with an
otherwise sloppy fingerprint (generic Intel MAC, desktop-junk EIR) was paged within ~2 s, while the
board advertising `0x000508` with a byte-perfect Pro name, EIR and SDP was never paged at all. The
Switch 1 accepts either. Neither console reads SDP before pairing, so SDP contents are not part of
this gate.

Two ordering traps, both about the *controller*, not the host stack:

- **Set the CoD before inquiry scan is enabled.** The ESP32 controller latches the CoD into its
  inquiry-response state at scan-enable and ignores later `Write_Class_of_Device`: the command
  returns success and the radio keeps answering the old value. Under BTstack, `gap_set_class_of_device()`
  before `hci_power_control(HCI_POWER_ON)` lands in the init sequence, which is correct by
  construction.
- **Do not try to reach it via GAP "limited discoverable" mode.** The ESP32 then answers only the
  *limited* inquiry code (LIAC), and the console inquires with the *general* one (GIAC), so you
  become invisible. The bit has to come from the CoD value itself. (Bluedroid actively fought this:
  `BTM_SetDiscoverability(GENERAL)` force-*clears* the limited bit on every scan-mode change, which
  is why the Bluedroid build needed a source patch to make that strip additive-only.)

## Input report 0x30 (standard full report)

Byte 0 is the report ID when sent raw. On the wire an interrupt-channel input report is
`A1 30 <body>`: the HID DATA|INPUT header `0xA1`, the report ID, then bytes 1 to N below.
BTstack's `hid_device_send_interrupt_message()` sends the buffer verbatim, so the caller supplies
that whole frame itself (`bt_pro_btstack.cpp send_report()`).

| Byte | Meaning |
|---|---|
| 0 | `0x30` (report ID) |
| 1 | Timer, increment every report, wraps 0x00 to 0xFF |
| 2 | Battery and connection. Use `0x80` (full battery, Pro, not powered) |
| 3 | Buttons, Right group |
| 4 | Buttons, Shared group |
| 5 | Buttons, Left group |
| 6 to 8 | Left stick (12-bit X,Y packed), neutral `00 08 80` |
| 9 to 11 | Right stick, neutral `00 08 80` |
| 12 | Vibrator input (`0x08`) |
| 13 to 48 | 6-axis IMU, Int16LE; all-zero when unused (NES needs none) |

### Button bit map

| Byte | x01 | x02 | x04 | x08 | x10 | x20 | x40 | x80 |
|---|---|---|---|---|---|---|---|---|
| 3 Right | Y | X | B | A | SR | SL | R | ZR |
| 4 Shared | Minus | Plus | R-Stick | L-Stick | Home | Capture | (none) | Chg-Grip |
| 5 Left | Down | Up | Right | Left | SR | SL | L | ZL |

The D-pad is individual bits in byte 5 (not a hat) for report 0x30.

### Stick 12-bit packing

x,y in 0 to 4095, center 2048 (0x800):

```c
b[0] =  x & 0xFF;
b[1] = ((x >> 8) & 0x0F) | ((y & 0x0F) << 4);
b[2] =  (y >> 4) & 0xFF;            // center 2048 packs to 00 08 80
```

### Neutral idle 0x30 (49 bytes incl. ID, no IMU)

```
30 00 80 00 00 00  00 08 80  00 08 80  08  <36 zero IMU bytes>
```

A 13-byte report with no IMU tail and `report30[12]=0x08` is fine for a non-motion controller.

## Input report 0x21 (subcommand reply)

Same prefix as 0x30 (bytes 0 to 12), then: byte 13 = ACK (`0x80` simple ack, `0x80|datatype` for
typed data such as `0x90` for SPI reads, NACK `0x00`), byte 14 = echoed subcommand id, bytes 15+ =
reply payload (up to 35). The canned prefix is `21 <pkt> 8E 84 00 12 01 18 80 01 18 80 80`.

## Output reports (host to device)

- `0x01`: rumble plus subcommand. `[1]` packet number, `[2..9]` rumble, `[10]` subcommand id,
  `[11..]` args (SPI sub-address at `[11]`/`[12]`). All handshake subcommands arrive here. Both
  BTstack's report-data callback and Bluedroid's OUTPUT event hand over the payload with the
  report-id byte already stripped, so the subcommand id is at `data[9]` and the SPI address at
  `data[10]`/`data[11]`. **BTstack gotcha:** it drops output reports whose length does not match
  the descriptor (`hid_report_size_valid()`), and the console's `0x01` frames are shorter than the
  48 bytes we declare - `hid_device_accept_truncated_hid_reports(true)` is required or every
  subcommand is silently discarded.
- `0x10`: rumble only; ignore.
- `0x80`: UART/handshake, USB-only; BT generally skips it. Ignore, or ack `0x81 <cmd>`.

## Canned 0x21 replies (byte 0 = report id 0x21)

Sent as `A1 21 <body>` on the interrupt channel. Prefix
`21 <pkt> 8E 84 00 12 01 18 80 01 18 80 80`, then `<ack> <subcmd> <payload>`.

- `0x02` Device info: ack `0x82`, subcmd `0x02`, firmware `03 48`, controller type `0x03` (Pro),
  then `0x02`, MAC (bytes 19 to 24, stamp the real BD_ADDR), `0x03`, zeros.
- `0x08` Set shipment: ack `0x80 0x08`.
- `0x03` Set input report mode: ack `0x80 0x03`. After this, stream 0x30 continuously.
- `0x04` Trigger elapsed time: ack `0x83 0x04`, then `00 6a 01 bb 01 93 01 95 01 ...`.
- `0x10` SPI flash read: ack `0x90`, subcmd `0x10`, then `addrLE(4) size(1) data[size]`. Dispatch by
  sub-address:
  - `0x603D` factory stick cal, size `0x19`:
    `F0 07 7F  F0 07 7F  F0 07 7F   F0 07 7F  F0 07 7F  F0 07 7F   0F 0F 00 00 00 00`
    (symmetric flat cal; passes the handshake).
  - `0x6080` factory config, size `0x18`:
    `5e 01 00 00 f1 0f  19 d0 4c ae 40 e1  00 00 00 00 00 00  ff ff ff ff ff ff 00 00`
  - `0x6098` stick params 2, size `0x12`:
    `19 d0 4c ae 40 e1  00 00 00 00 00 00  ff ff ff ff ff ff 00 00`
  - `0x6020` factory IMU cal, size `0x18`: zeros.
  - `0x6050` controller colors, size `0x18`: zeros.
  - `0x8010` / `0x8028` user stick/IMU cal: return `0xFF` for the magic so the Switch falls back to
    factory cal.
- `0x21` Set NFC/IR config: ack `0x80 0x21` plus 34 zero bytes. Flip the paired flag here and switch
  from empty reports to full 0x30 streaming.
- `0x30` Set player lights: ack `0x80 0x30`.
- `0x40` Enable IMU: ack `0x80 0x40`.
- `0x48` Enable vibration: ack `0x80 0x48`.
- `0x01` BT manual pairing: not part of the wireless Change-Grip flow; ack `0x80 0x01` if seen.
- Any unhandled subcommand: always answer something (ack `0x80`, echo id) or the Switch stalls.

## Handshake order and timing

1. Until paired, stream a tiny empty report (`00 <timer>`) about every 100 ms to keep the link
   alive.
2. The Switch issues, over output 0x01, roughly: `0x02` info, `0x08` shipment, `0x10` SPI reads
   (stick cal), `0x03` set mode 0x30, `0x04` elapsed, `0x40` IMU, `0x48` vibration, `0x30` lights,
   `0x21` NFC/IR. Answer each within a few ms (synchronously in the data event).
3. After `0x03` to `0x30` is acked, stream full 0x30 at about 60 Hz continuously or the controller
   is dropped. NSO NES needs no IMU or rumble, but you must still ack 0x40/0x48 during the
   handshake.
4. Increment the timer byte every report.

## Link-layer power: never slave-initiate sniff

A real Pro Controller is a BT slave that never initiates sniff. It lets the master (Switch, 8BitDo,
PC) drive power management and only accepts the master's sniff. Stock Bluedroid's HID-device power
spec does the opposite: it slave-initiates sniff about 5 s after connect, on idle, and on "busy"
(the last fires on every report of a 60 Hz stream). The Switch tolerates this, but the 8BitDo NES
receiver refuses it (HCI status `0x24`, "LMP PDU not allowed") and the retry storm tears the link
down and re-pairs repeatedly, so the receiver never holds a stable connection.

On BTstack this is free: it never initiates sniff unless the application asks. We allow the policy
(`gap_set_default_link_policy_settings(... | LM_LINK_POLICY_ENABLE_SNIFF_MODE)`) so a master's
sniff is still accepted, and set the SDP record's SSR fields to `0xFFFF` so we request no sniff
subrating either.

(Historical: under Bluedroid this needed a build-time patch, `tools/patch_bluedroid_sniff.py`, to
null all three sniff initiations in the `const` `bta_dm_pm_spec[]` HD entry - there was no runtime
API or Kconfig for it. `esp_bt_gap_set_qos()` alone did not fix it; it only momentarily woke the
link before BTA re-sniffed. See git history before the BTstack switch.)

## Connection direction: passive first, then a bounded device-initiated "kick"

After authentication, the two HID L2CAP channels (control PSM `0x11`, interrupt `0x13`) must open.
Hosts differ in who they expect to open them:

- The Switch Change Grip/Order screen and the 8BitDo Retro Receiver open both channels themselves,
  promptly after auth.
- BlueRetro mimics the console's *reconnect* role: it expects the controller to behave like a real
  Pro (which advertises `HIDReconnectInitiate` and opens the channels itself). If the device stays
  passive it waits forever and gives up after ~30 s.

So `bt_pro_btstack.cpp` starts passive (host-initiated connects just work: BTstack's `hid_device`
auto-accepts incoming CTRL/INTR) and arms a one-shot "kick" timer on pairing complete, on a bonded
boot, and on disconnect: if the host has not opened HID within a 1.5 s grace window, the device
calls `hid_device_connect()` itself. A successful `HID_SUBEVENT_CONNECTION_OPENED` cancels the
kick. The grace window also avoids racing a host that is opening its own connection.

Retries are bounded in two tiers: 4 fast attempts, each paced by the page's own completion and so
about 5 s apart, then a slow re-page every 30 s, 6 of those, then passive. The slow tier covers a
host that is not listening yet. A stick powered on before the console or dock spends all four fast
attempts in the first ~20 s, and a host that accepts only controller-initiated reconnects then
waits for a page that never comes. In gameplay the app's 90 s unconnected deep sleep usually ends
the sequence before the slow budget does; waking reboots and pages from the top.

Grace-window sizing: it must be long enough that hosts which open both channels themselves (Switch
console, 8BitDo Retro Receiver - both well under 1 s) always win, but short enough to beat
BlueRetro, which opens CTRL and waits only ~2 s for the controller's INTR before tearing down and
retrying. A 3 s grace loses that race and the two sides then collide (orphan L2CAP channel,
subcommand replies lost, link dropped after ~30-60 s, repeat).

BlueRetro is a third pattern: it does open both channels itself, but only ~3 s after auth (it runs
an SDP query first), and it opens CTRL within milliseconds of the SSP link key - before encryption
has settled.

## Input report modes: 0x3F by default, 0x30 on request

A real Pro Controller powers up in simple input mode - report `0x3F` (2 button bytes, hat, four
16-bit axes), sent on state change - and only streams full `0x30` reports after the host selects
that mode with subcommand `0x03`. The Switch consoles and the 8BitDo Retro Receiver send `0x03 0x30`
during their handshake; BlueRetro never sends `0x03` and reads `0x3F` reports. The firmware
therefore starts every connection in `0x3F` mode (sent on change plus a ~100 ms keepalive) and
switches to the continuous ~66 Hz `0x30` stream when subcommand `0x03` asks for it.

## ESP32 / BTstack notes

- Send all input reports on the interrupt channel, as a self-framed `A1 <report_id> <body>` buffer
  passed to `hid_device_send_interrupt_message()`. Sending is gated: call
  `hid_device_request_can_send_now_event()` and build the frame in the
  `HID_SUBEVENT_CAN_SEND_NOW` handler.
- `hid_device_accept_truncated_hid_reports(true)`, or the console's short `0x01` output reports are
  silently dropped and no subcommand ever arrives.
- Classic-only: release BLE memory (`esp_bt_controller_mem_release(ESP_BT_MODE_BLE)`) and enable
  the controller in `ESP_BT_MODE_CLASSIC_BT` to free RAM and avoid coexistence issues.
- BTstack is single-threaded: call its API only from the run loop, and bring the stack up **on the
  run-loop task** - `btstack_run_loop_init()` records its caller as the task to notify for all
  cross-thread work, including the VHCI transport's own packet delivery. Initialize it from the
  wrong task and the stack silently never reaches `HCI_STATE_WORKING`. Hand work in from other
  tasks with `btstack_run_loop_execute_on_main_thread()`.
- Stamp the device's real BD_ADDR (`gap_local_bd_addr()`) into the 0x02 device-info reply MAC field.
- Do not go silent between handshake packets; answer subcommands within a few ms.
- Do **not** define `ENABLE_HCI_CONTROLLER_TO_HOST_FLOW_CONTROL`. This controller does not implement
  it (`Read_Local_Supported_Commands` octet 10 = `0xFC`: `Set_Controller_To_Host_Flow_Control` and
  `Host_Buffer_Size` both clear) and refuses `Host_Buffer_Size` on the wire with status `0x11` at any
  parameters, while stubbing the flow-control enable out as success. BTstack believes the lie and
  then answers every inbound ACL packet with a `Host_Number_Of_Completed_Packets` nobody asked for,
  which preempts every other command in `hci_run()`. The VHCI transport does its own backpressure.
- Debugging: `hci_dump_init(hci_dump_embedded_stdout_get_instance())` puts a full HCI trace on the
  serial console (`BTNA_HCI_DUMP` in `bt_pro_btstack.cpp`, off by default). This is the only way to
  see a handshake; pairing failures happen entirely below the app log.

## When a Switch 2 refuses to pair with anything

A Switch 2 can wedge into a state where it **refuses SSP with every device**, including commercial
controllers: it pages you, completes the ACL, sets your link supervision timeout, then detaches with
**Authentication Failure (0x05) ~50-90 ms in, having never sent a single SSP packet**: no IO
Capability Request, no User Confirmation, no Link Key Notification.

**Power-cycle the console** (hold Power → Power Options → Turn Off; sleep is not enough).

This signature is indistinguishable from a firmware bug and will happily absorb days. Two things
that fake it, to rule out before believing your own code is at fault:

- Reproduce with a device you did not write. If a stock controller is rejected too, the console is
  the variable.
- On a BlueZ host, check an auto-accept SSP agent is registered. bluetoothd's default agent rejects
  the Just-Works confirmation and produces the identical 0x05.

## Sources

- dekuNukem/Nintendo_Switch_Reverse_Engineering: `bluetooth_hid_notes.md`,
  `bluetooth_hid_subcommands_notes.md`, `spi_flash_notes.md`
- NathanReeves/BlueCubeMod: `Firmware/BlueCubeModv2/main/main.c`
- BTstack (`bluekitchen/btstack`): `src/classic/hid_device.h`, `example/hid_keyboard_demo.c`
- Other BTstack-based Pro Controller emulators: `DavidPagels/retro-pico-switch`,
  `Wilstride/PicoSwitchController` (both Pico W; same GAP/SDP parameter choices)

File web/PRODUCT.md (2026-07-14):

# Product

## Register

product

## Users

Owners of the **Bluetooth NES Advantage** mod, a hardware+firmware kit that turns
the classic NES Advantage arcade stick into a wireless controller for the Switch,
Switch 2, and BLE hosts, plus the maker who builds and sells the kit. Mostly
retro-gaming hobbyists. They open this page at a **desk or bench**, on a desktop
or laptop, with the stick in front of them, usually to do one focused thing:
change how it behaves or confirm the hardware works.

Primary jobs on any visit:

1. **Test the stick.** Put it in config mode, watch every button, the D-pad, the
   P1/P2 switch, and the turbo dials light up live so a buyer or builder can
   confirm the hardware end to end without a console.
2. **Configure it.** Pick the transport (Classic Switch Pro / BLE), the button
   profile, and the directional mode; forget a paired host; reboot.
3. **Update firmware** over the air, and read the live device log.

## Product Purpose

The single Web Bluetooth control panel for the mod's BLE config server
(`firmware/main/bt_config.cpp`). It is the main interface a buyer touches after
the solder work is done, so it doubles as the product's face. Success = a builder
connects on the first try, immediately sees the controller respond button for
button, and configures it without a manual.

## Brand Personality

An 8-bit console you climb inside. Three words: **molded, tactile, diegetic.** It
should feel like the inside of a grey front-loader NES, the two-tone plastic, the
red racing stripe, the chunky POWER/RESET slides, the cartridge slot, honest
mono readouts on a dark screen. The heritage is worn as **industrial design**,
not decoration: the console *is* the chrome.

## Anti-references

- Kitsch retro: pixel/8-bit display fonts, chiptune skeuomorphism, scanline
  filters slapped on everything, `Press Start` cliches.
- Generic dark-neon "gamer" RGB dashboards.
- SaaS-cream / warm-paper backgrounds, glassmorphism, gradient-and-glow decor.
- Marketing scaffolding: tracked-uppercase eyebrows, hero-metric templates, 01 /
  02 / 03 section numbers, over-glossy buttons.
- Nintendo trade dress or logos. The look is *evocative of* an era's industrial
  design, never a counterfeit of a brand.

## Design Principles

1. **The controller is the hero.** The live button tester is the thing a builder
   came to see; it reads at a glance and never lies about hardware state.
2. **Read like the console's own panel.** Molded grey surfaces, a single red
   accent, hard edges, mono readouts on a dark "screen." No decoration that
   isn't signal.
3. **Follow the hardware.** The P1/P2 indicator, turbo meter, and battery all
   mirror what the stick physically reports; nothing is invented UI state.
4. **Robust over pretty when they conflict.** Web Bluetooth on Linux is flaky, so
   the connection self-heals (retry + auto-reconnect) rather than looking nice
   and failing.
5. **One self-contained file.** No build, no external requests; served as-is over
   localhost/HTTPS and stays forkable.

## Accessibility & Inclusion

- Light molded-grey theme (used bench-lit at a desk). Contrast verified: body and
  labels hit >= 4.5:1 on grey; the red accent is used at weights that clear 3:1
  for large text / UI, near-white text on red fills.
- Full `:focus-visible` on every control; native form controls (select, range,
  file, text) for assistive-tech support.
- `prefers-reduced-motion` honored: the button-tester still updates (it's state,
  not decoration), but entrance and view-transition motion collapse to instant.
- Not color-only: pressed buttons carry a filled/labeled state, the P1/P2 switch
  shows the player number as text, connection state is labeled, turbo shows a
  numeric Hz readout beside the meter.
</content>
</invoke>

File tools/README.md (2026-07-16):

# tools/

Host-side helpers for firmware development.

## Serial monitor and flashing: benchmux

Firmware bring-up (owning the UART, tailing the boot log, flashing without stopping the monitor)
uses **benchmux**, a standalone bench serial proxy, rather than a script bundled here. Only one
process can own a serial port, so benchmux owns it and tees everything to a shared logfile; any
number of readers follow it live while `flash` coordinates the port handoff, so nothing is stopped
by hand. `tail -f` survives flashes; it pauses, then the fresh boot streams in.

benchmux ships `serial_proxy.py` (USB serial console + flash) and `ble_proxy.py` (BLE console +
OTA). Run it by path, or symlink it onto `PATH`:

```bash
serial_proxy.py monitor --port /dev/ttyUSB0                       # own the port, tee to /tmp/serial_proxy.log
tail -f /tmp/serial_proxy.log                                     # watch live, any number of readers
serial_proxy.py flash --flash-cmd 'pio run -e wroom32 -t upload'  # build + upload, monitor stays up
serial_proxy.py reset                                             # reboot the chip (pulse DTR/RTS)
serial_proxy.py send help                                         # inject a console line
serial_proxy.py status                                            # proxy pid / port / log
serial_proxy.py stop                                              # stop the proxy
```

With a `platformio.ini` present, `flash` defaults to `pio run -t upload`; pass `--flash-cmd` to pin
the env (as above) or drive another toolchain. The proxy auto-reopens when the USB-serial adapter
re-enumerates across `ttyUSBn` renumbering; pin one adapter with `--port` (a `/dev/serial/by-id/*`
substring, e.g. `TC2030`, or an exact path). Log defaults to `/tmp/serial_proxy.log`
(`--log` / `SERIAL_PROXY_LOG`). `pio device monitor` needs a real TTY; reading the logfile is the
scriptable path.

## Pre-build Bluedroid patches (removed)

This directory used to hold `patch_bluedroid_*.py`, PlatformIO `extra_scripts` that edited the
Bluedroid Classic stack in place to make its HID device behave like a real Pro Controller. The
Classic transport now runs on BTstack, which does all of it natively, and Bluedroid's Classic half
is compiled out - so the patches are gone. They are in git history if a Bluedroid Classic path is
ever revived. See [`../docs/FIRMWARE.md`](../docs/FIRMWARE.md) "Two Bluetooth host stacks" and
[`../firmware/components/btstack/README.md`](../firmware/components/btstack/README.md).

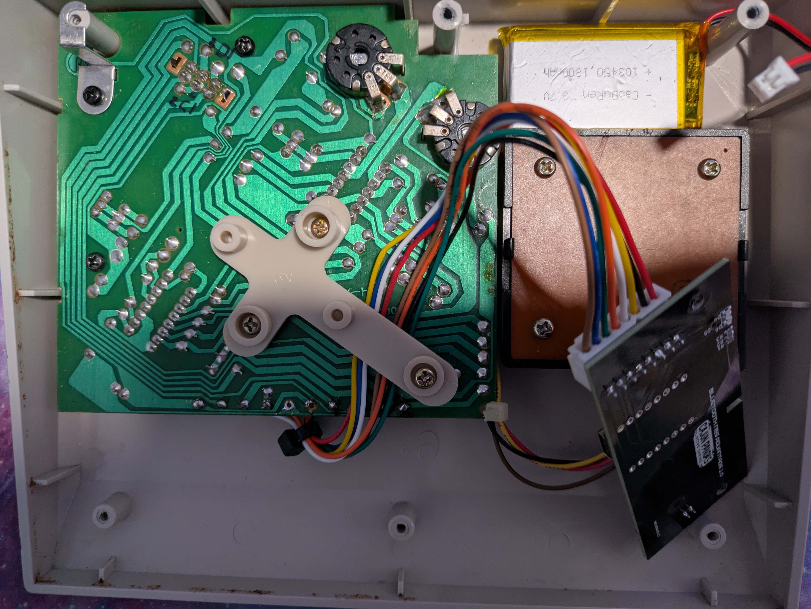
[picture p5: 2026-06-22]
docs/images/battery_placement.jpg

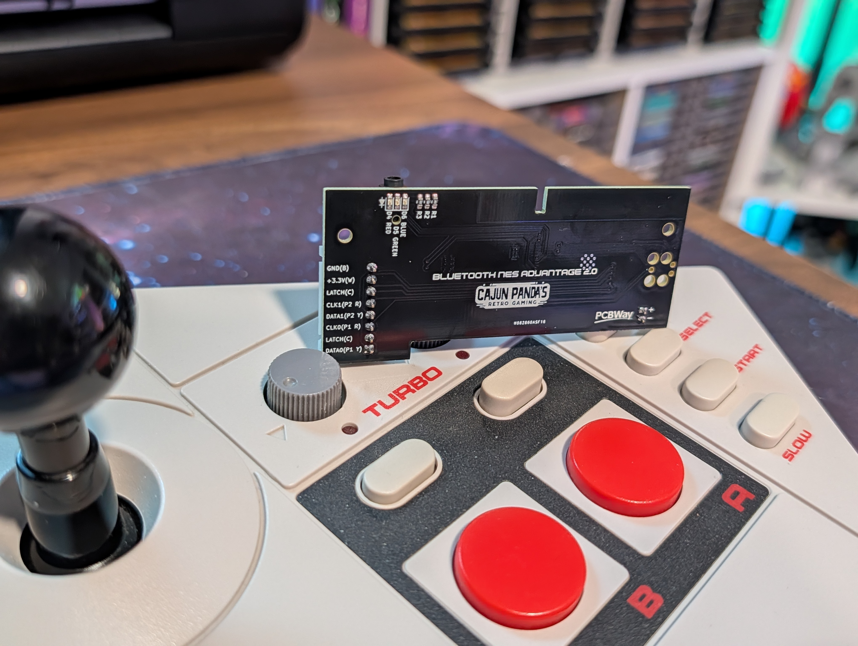
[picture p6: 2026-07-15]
docs/images/hero-1.jpg

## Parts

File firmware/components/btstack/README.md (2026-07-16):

# BTstack (vendored subset)

Pinned copy of [BTstack](https://github.com/bluekitchen/btstack) **v1.8.2** (tag, 2026-06-15),
used as the Bluetooth Classic host stack for the Switch Pro Controller transport
(`main/bt_pro_btstack.cpp`). The BLE gameplay transport and the config/OTA boot mode remain on
ESP-IDF Bluedroid; exactly one host stack is initialized per boot on the shared controller
(VHCI). Motivation and bring-up notes: `docs/switch_pro_protocol.md` and the project history —
Bluedroid's inbound pre-pairing behavior is rejected by the Switch 2 (drop reason 0x05 before
SSP) and is not fixable from the app; BTstack-based Pro emulators are known to pair.

## Layout

- `upstream/` — unmodified files from the v1.8.2 tag (subset: HCI/L2CAP/SDP/HID-device core,
  FreeRTOS run loop, stdout HCI dump; all headers). To add a file the linker wants, copy it
  from the same tag.
- `port/` — from upstream `port/esp32/components/btstack/`, with one local change:
  `hci_transport_esp32_vhci.c` enables the controller in `ESP_BT_MODE_CLASSIC_BT` (not BTDM)
  when built Classic-only, because the transport boot releases the BLE controller memory first
  (marked `// btna:`).
- `include/btstack_config.h` — ours (Classic-only, quiet-slave L2CAP defaults, NVS link keys).
- `CMakeLists.txt` — ours.

## License

BTstack is Copyright BlueKitchen GmbH, free for personal/non-commercial use only (see the
header in any upstream file; clause 4 forbids commercial use). This project is a personal
open-source hardware mod, which fits. A commercial fork of this project would need a BTstack
license from BlueKitchen (or a different stack).

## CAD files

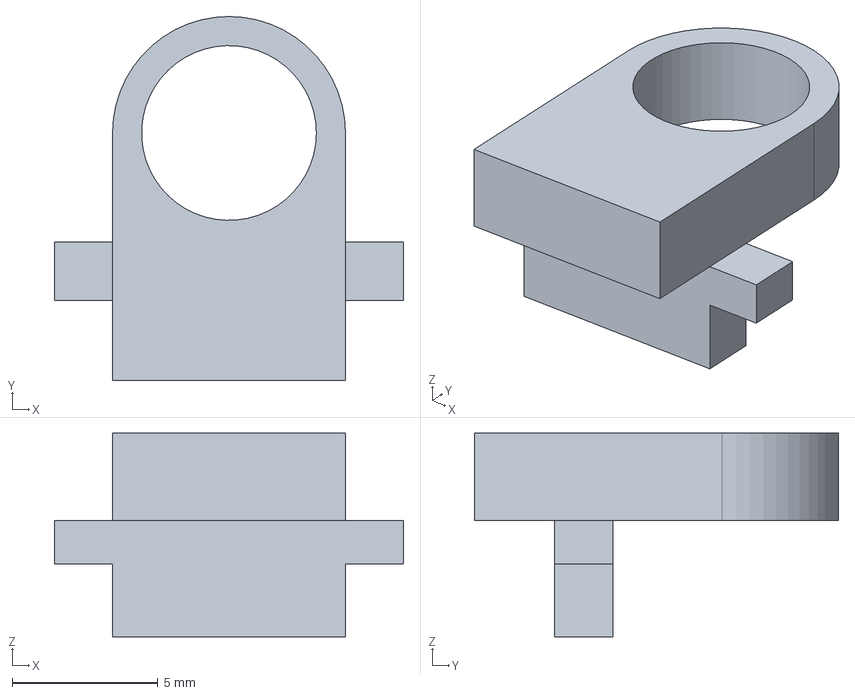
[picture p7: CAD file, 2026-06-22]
hardware/bt-nes-advantage-jack-plug/bt-nes-advantage-jack-plug.FCStd
12.0 x 12.5 x 7.00 mm

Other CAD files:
hardware/bt-nes-advantage-jack-plug/bt-nes-advantage-jack-plug.stl

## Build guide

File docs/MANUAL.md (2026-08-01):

# Manual

How to use a Bluetooth NES Advantage. Everything is driven from the stick's own controls; there
are no added buttons.

## Charging

Plug a 5 V supply into the DC jack. The green LED blinks while charging and is solid when full.
You can play while charging.

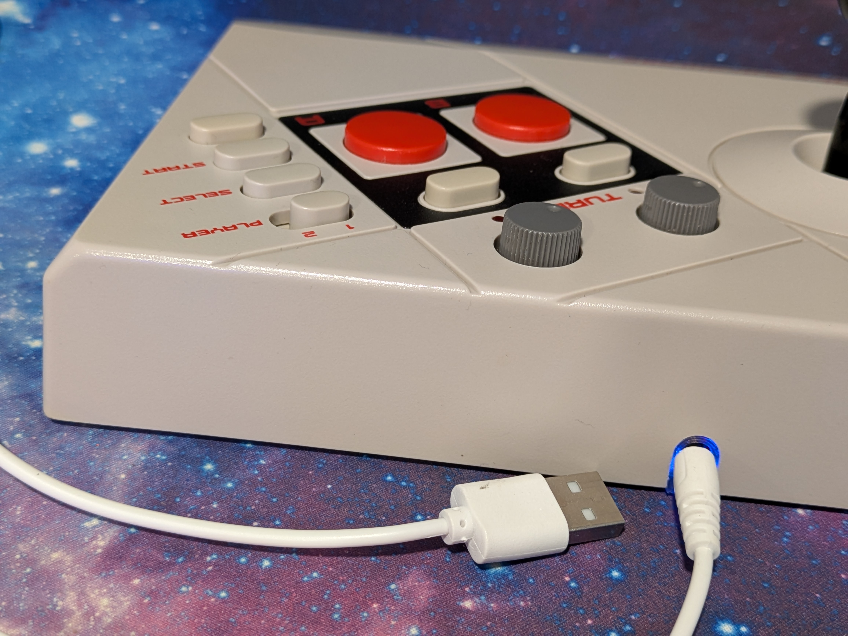
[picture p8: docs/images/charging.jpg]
Charging


## Pairing

1. Charge it if needed.
2. Pick the mode with a gesture (see Gestures below): Switch / Receiver (default) or BLE.
3. Pair:
   
   - **Nintendo Switch and Switch 2:** open Controllers, then Change Grip/Order. The stick appears
     as a Pro Controller. The blue LED blinks while pairing and is solid once connected.
   
   - **8BitDo Retro Receiver:** put the receiver in pairing mode and wake the stick. Pairing takes
     a few seconds (the stick waits for the host briefly, then completes the connection itself).
   
   - **BlueRetro (BT Classic):** press BlueRetro's pair button and wake the stick. Expect a few
     connect/disconnect cycles for the first ~20 seconds while BlueRetro's pairing mode settles;
     the link then holds. (BlueRetro also works over the BLE transport.)
   
   - **BLE (PC, phone, emulator):** switch to BLE mode, then pair "NES Advantage" from the
     device's Bluetooth menu.
4. Play. The stick reconnects to the last host automatically on wake.

**Nintendo Switch 2:** pairs directly from Change Grip/Order, exactly like a Switch 1. No adapter
needed.

**If a Switch 2 won't pair with anything**, including controllers that worked yesterday, power it
off completely (hold Power, then Power Options, Turn Off) and try again. Sleep is not enough. A
Switch 2 in this state connects to a controller and then drops it a fraction of a second later,
every time.

## Gestures

Hold the listed buttons together for about 5 seconds, then release. The LED blinks to confirm.
Gestures work any time during play. For any gesture that uses A or B, turn the Turbo dials off
first: turbo pulses those buttons, so the hold won't register with it on.

| Hold for 5 s | Does | Confirm |
| --- | --- | --- |
| Start | Sleep (power down) | LEDs off |
| Select | Forget the paired host, re-pair from scratch | Blue blinks |
| Select + Start | Switch mode: Switch/Receiver or BLE (restarts) | Blue blinks |
| A + B + Up | Cycle button profile | Red blinks the profile number |
| A + B + Down | Cycle directional mode | Red blinks the mode number |
| A + B + Select | Enter config / firmware-update mode (restarts) | Blue blinks 3 times |

Hold **Start** to wake from sleep.

## Buttons the NES stick doesn't have

The Switch wants buttons an NES Advantage never had. Hold **Select** and press another button to
reach them. Unlike the gestures above these are instant, not 5-second holds, and they work mid-game:

| Hold Select, press | Sends |
| --- | --- |
| Start | Home |
| Up | ZL + ZR (opens the menu in NSO retro games) |
| Left | ZL |
| Right | ZR |
| Down | Capture (hold to record a clip) |

The button stays down for as long as you hold the chord, so Select + Down held records a video clip
the same way holding Capture on a Pro Controller does.

**You have a short window to start the chord**: 200 ms out of the box, about a fifth of a second.
Press Select and the other button together, or in quick succession. Hold Select for longer than that
without pressing anything and it settles into being an ordinary Minus, held for as long as you hold
it, and the next button you press stays itself.

You can change the window, or turn chords off entirely, in the **Configure** tab of the config page
(see [Configuration and firmware updates](#configuration-and-firmware-updates) below):

| Setting | What you get |
| --- | --- |
| **Off** | Select is an ordinary button, exactly like A or Start. No chords at all. |
| **100 to 500 ms** | The window above. Shorter is snappier for Select; longer is easier for chords. |
| **Hold** | No limit: reach for a chord whenever. Minus only registers when you let go, and can never be held. This is how 2.2 and earlier behaved. |

Chords are a Switch feature. In **BLE mode they don't exist**: the buttons they produce are ones a PC
or emulator has no use for, so there is nothing to gain and a holdable Select to lose. The setting
only appears in Switch/Receiver mode, and Select in BLE mode is always an ordinary button.

A few things worth knowing:

- **Press Select first**, then the other button. A direction you were already holding keeps steering
  — running right and tapping Select stays Right + Minus, it won't fire ZR. Let go of the direction
  and press it again if you want the chord.
- **Turn the slow-motion switch off** to use Select + Start. It pulses Start in hardware, the same
  way the Turbo dials pulse A and B, so it fires Home over and over. (It also pulses Plus into the
  game, so it isn't much use in play regardless.)
- The Turbo dials don't interfere: no chord uses A or B.
- Holding Select + Start for 5 seconds still switches mode, as above. You'll see the Switch's Home
  menu open on the way, which doesn't matter — the stick is reconnecting to something else anyway.

## LEDs

| LED | Meaning |
| --- | --- |
| Blue solid | Connected to a host |
| Blue blinking | Pairing, waiting for a host |
| Blue off | Idle, not connected |
| Green blinking | Charging |
| Green solid | Fully charged |
| Red blinking | Battery low (under 20%) |
| Green and blue alternating, fast | Config / firmware-update mode |

In config / firmware-update mode the green LED blinks the whole time, alternating with blue, so you
can tell at a glance that the gesture took. Once the browser connects, blue goes solid and green
keeps blinking.

## Button profiles and directional modes

The stick remembers your choices per connection mode.

Button profiles (how NES A/B map onto the host):

| Mode | Profile 1 | Profile 2 |
| --- | --- | --- |
| Switch / Receiver | Literal: A to A, B to B | Comfort: A to B, B to Y |
| BLE | Default: A to 1, B to 2 | Blue Retro: A to 1, B to 4 |

Every profile is named for where it puts the buttons, so the name and the picker agree with what
the host receives. Select and Start never move, in any profile.

In Switch / Receiver mode the stick is a Pro Controller, so the destinations are its face buttons.
**Literal** sends NES A as A and NES B as B. **Comfort** shifts both one place around the diamond:
pressing NES A sends **B**, pressing NES B sends **Y**.

Start with Literal. Switch Online's NES games and the 8BitDo Retro Receiver both read the Pro
Controller's A and B as the NES A and B, so Literal is what puts NES A on A. Comfort is there for
games and emulators that expect the two buttons on the lower-left pair instead; if your jump button
comes out on the wrong button, that is the one to try.

In BLE mode the stick is an ordinary gamepad, so the host sees **numbered** buttons rather than
named ones, and the profiles say which number each NES button becomes. Which number means what is
up to the game or emulator; most let you rebind. **Default** is the one to start with. **Blue
Retro** moves only NES B, from 2 to 4, for BlueRetro adapters over BLE.

Directional modes (where the joystick goes):

| Mode | 1 | 2 | 3 |
| --- | ----- | --- | ---- |
| Switch / Receiver | D-Pad | Left stick | Both |
| BLE | D-Pad | Axes | Both |

Most NES games on Switch want D-Pad. Use the stick/axes modes for games or menus that expect an
analog stick.

## Player 1 / Player 2 (take-turns play)

The original player-select slider still works. It is built for hot-seat games like Super Mario
Bros., where two players share one stick. What it can do depends on the host, because one Bluetooth
radio can only be one controller to a console receiver:

| Connected to | Take-turns? | How |
| --- | --- | --- |
| PC / emulator (BLE) | Yes | The stick shows up as two gamepads. Flip the slider to hand off; map each gamepad to a player in the emulator. |
| BlueRetro | Yes | Leave the slider on P1 and double-map the buttons to both wired ports in BlueRetro's config. |
| Nintendo Switch / Switch 2 | No | One Pro Controller is one player. The slider picks which player you report as. |
| 8BitDo Retro Receiver | No | One receiver occupies one NES port. Same as above. |

Set the slider before or while you pair.

## Sleep and battery

- Playtime on a full 1800 mAh cell: about 17 hours in Switch/Receiver mode, about 37 hours in BLE
  mode. Standby lasts months.
- Manual sleep: hold Start for 5 s. Hold Start to wake.
- Auto-sleep after 90 seconds with no host, or 5 minutes idle while connected. Stays awake while
  charging.
- Sleep is a deep sleep with the buttons still monitored; waking reconnects in about a second.

## Configuration and firmware updates

The controller has a built-in web app for testing every input, changing how it behaves, and
flashing new firmware — all over Bluetooth, no cable. It runs in Chrome or Edge (Web Bluetooth); on
iPhone use a Web BLE browser such as Bluefy.

### Enter config mode and connect

1. Hold **A + B + Select** for 5 s. The stick restarts into config mode and advertises as "NES
   Advantage Config"; the blue LED blinks while it waits.
2. Open the hosted config page at
   **<https://cajunpanda.github.io/bluetooth-nes-advantage/>**, click **Connect over Bluetooth**,
   and pick **NES Advantage Config**. The blue LED goes solid once connected.

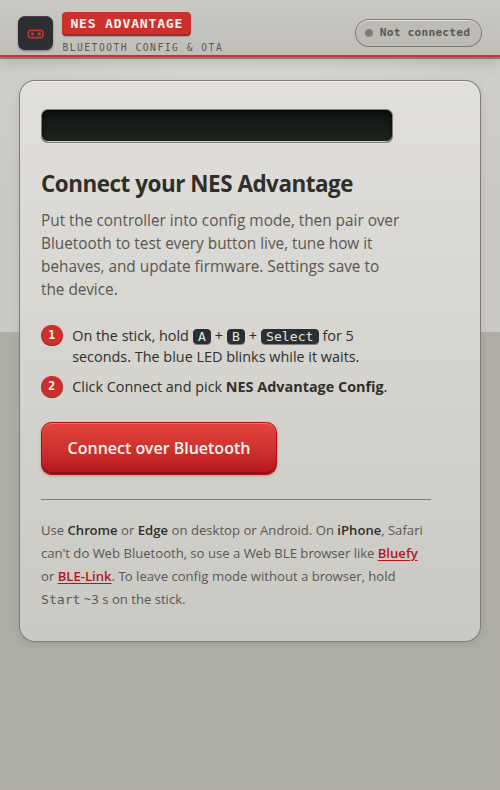
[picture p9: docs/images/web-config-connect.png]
The web config page connect screen


The stick also boots straight into config mode if it cannot reach the controller board (a harness
or solder fault): the red LED blinks and the page shows "No controller detected".

### Test

The **Test** tab mirrors the stick live. Every button, the D-pad, Select and Start, the P1/P2
slider, and both turbo dials light up as you use them, with each turbo rate shown in Hz and a
battery gauge below. Toggle the player-select slider to check each side. Use this to confirm a
fresh install or track down a dead input.

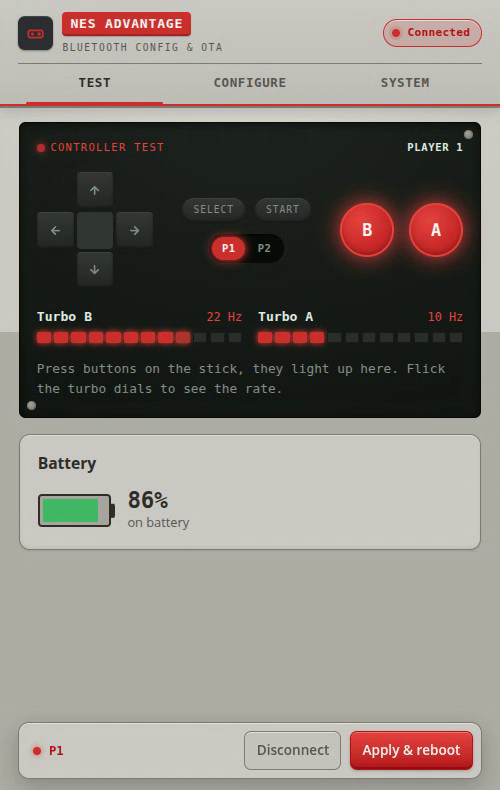
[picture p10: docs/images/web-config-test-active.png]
The Test tab lighting up as buttons are pressed


### Configure

The **Configure** tab sets the per-mode options: **Transport** (Switch/Receiver or BLE), **Button
profile**, **Directional mode**, and **Select chords**. These are the same choices as the on-stick
gestures, alongside a readout of the device name, firmware version, and running OTA slot. Change what
you want and press **Apply & reboot** (bottom left) to save; the stick restarts into the new settings.

**Select chords** is the window described in
[Buttons the NES stick doesn't have](#buttons-the-nes-stick-doesnt-have). It is a Switch feature, so
it greys out when Transport is set to BLE. Note that the **Test** tab shows the raw buttons coming off the stick, before
chords are applied, so Select always lights up there the moment you press it no matter what this is
set to.

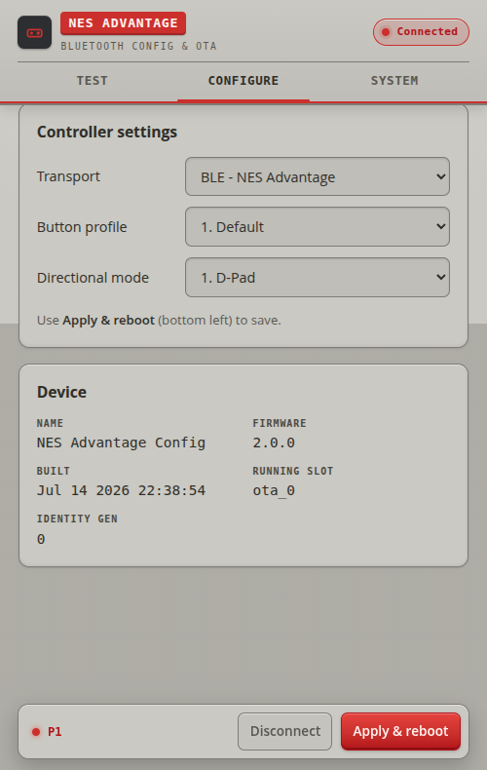
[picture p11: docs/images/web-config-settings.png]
The Configure tab with transport, profile, and directional-mode settings


### Firmware updates (OTA)

The **System** tab flashes new firmware over the air. Drag a `firmware.bin` onto the cartridge slot
(or tap to choose one) and press **Flash firmware**. Keep the page open until the device reboots
into the new image. The update is written to the second OTA slot and SHA-256 verified before the
boot partition switches, so a bad upload leaves the running firmware untouched. The same tab has a
live device console — the stick's log plus the wired console commands (`help`, `get`, `batt`,
`diag`, `profile`, …) for troubleshooting.

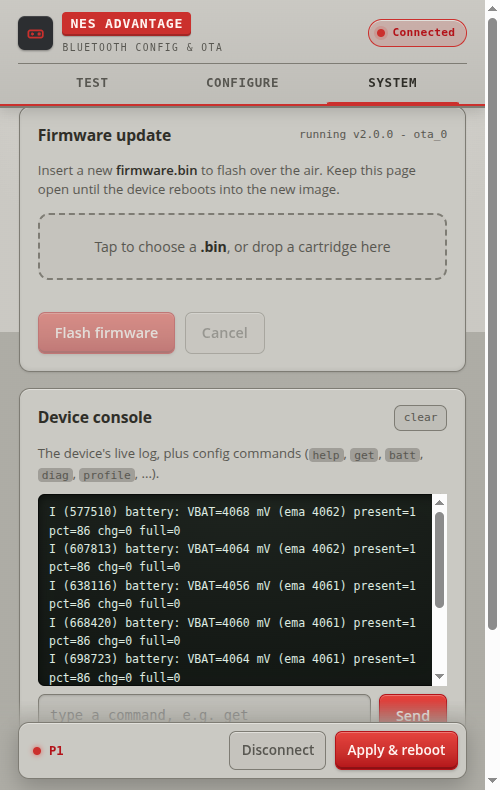
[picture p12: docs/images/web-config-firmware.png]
The System tab: firmware update slot and live device console


### Sending a link log for support

If the stick won't pair with a host at all, or pairs but never reconnects on its own, it keeps a
record of what happened. That record is what makes the fault diagnosable without your host on
hand, which matters most for adapters and docks we have never tested against.

1. Reproduce the fault: turn everything on the way you normally do and let the stick fail to
   connect.
2. Without power-cycling the stick, hold **A + B + Select** for 5 seconds to enter config mode.
3. Open the config page, connect, and press **save link log** on the **System** tab.
4. Send the downloaded text file with your description.

The file lists pairing and reconnect attempts from the last few sessions: which host tried and what
kind of device it says it is, what it asked for during pairing, whether it asked for the stick's
stored pairing key, and why each attempt ended. It holds device addresses and status codes only,
no personal data.

### Leave config mode

Hold **Start** for about 3 s to return to normal play, or wait — it exits after 5 idle minutes. See
[`../web/README.md`](../web/README.md) for the GATT contract and full browser-support notes.

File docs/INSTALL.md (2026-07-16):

# Installation

How to install the Bluetooth NES Advantage board into an NES Advantage (NES-026) controller. No
case cutting: the board replaces the controller's cable and its jack sits in the original cable
hole. This covers both a board you built yourself and a prebuilt board or kit.

## What you need

- The Bluetooth NES Advantage board, flashed with firmware. A self-built board needs its first flash
  over the Tag-Connect cable (see [FIRMWARE.md](FIRMWARE.md)); kit and prebuilt boards ship
  pre-flashed.
- A 1S LiPo battery (JST-PH, 1500 to 2000 mAh) and an 8-pin JST-XH harness cable. See
  [Accessories and tools](HARDWARE.md#accessories-and-tools) for specific parts.
- A soldering iron, insulating tape, and a small screwdriver.
- The 3D-printed DC jack plug (step 7).

## 1. Open the controller

Remove the screws in the base and lift off the metal back plate. Full teardown video:
[NES Advantage Clean and Teardown](https://youtu.be/Sw1IDFrGwic).

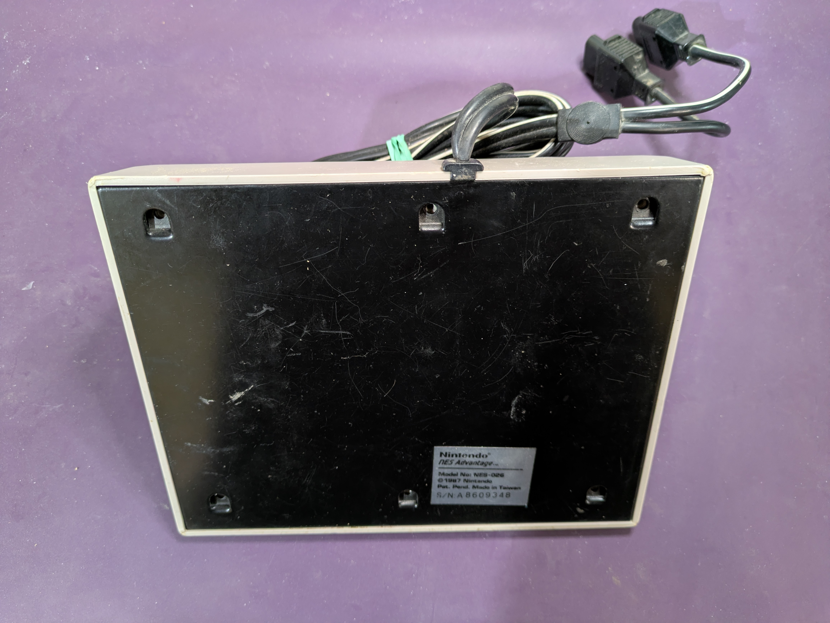
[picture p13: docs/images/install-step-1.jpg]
Controller closed, back plate and original cable

Controller opened, back plate removed

## 2. Remove the original cable

The controller's flat cable is soldered to a row of pads along the bottom edge of the internal PCB.
Desolder it. Those same pads carry the signals the board reads.

Internal PCB with the original cable attached

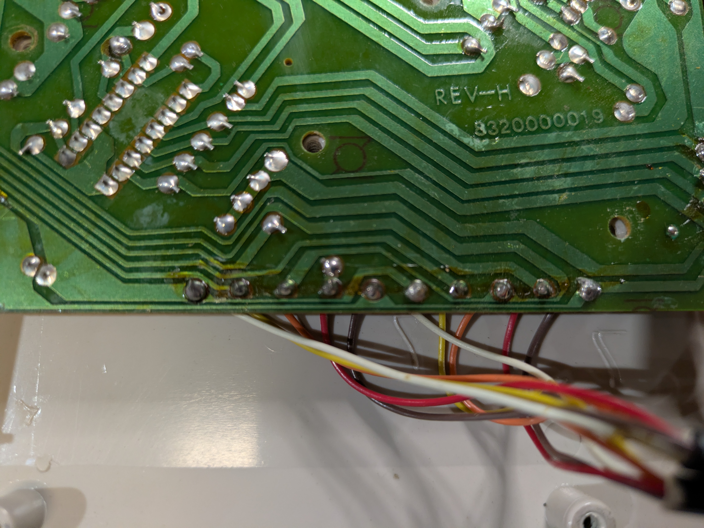
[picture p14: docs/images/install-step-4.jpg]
Harness wires soldered to the board pads


## 3. Solder the harness

Solder the 8-pin JST-XH harness to the controller. J2 pinout, matching the labels on the board silk:

| J2 pin | Signal  | Controller side |
| --- | --- | --- |
| 1 | DATA_0  | P1 4021 serial out |
| 2 | LATCH | P1 4021 latch |
| 3 | CLOCK_0 | P1 4021 clock |
| 4 | DATA_1  | P2 4021 serial out |
| 5 | CLOCK_1 | P2 4021 clock |
| 6 | LATCH | P2 4021 latch |
| 7 | +3.3V | Controller supply  |
| 8 | GND | Controller ground  |

The supply wire carries 3.3 V, and the latch line gets its own conductor to each shift register (J2
pins 2 and 6 are the same net). The controller's internal schematic is in
[`nes_advantage_schematic.svg`](nes_advantage_schematic.svg).

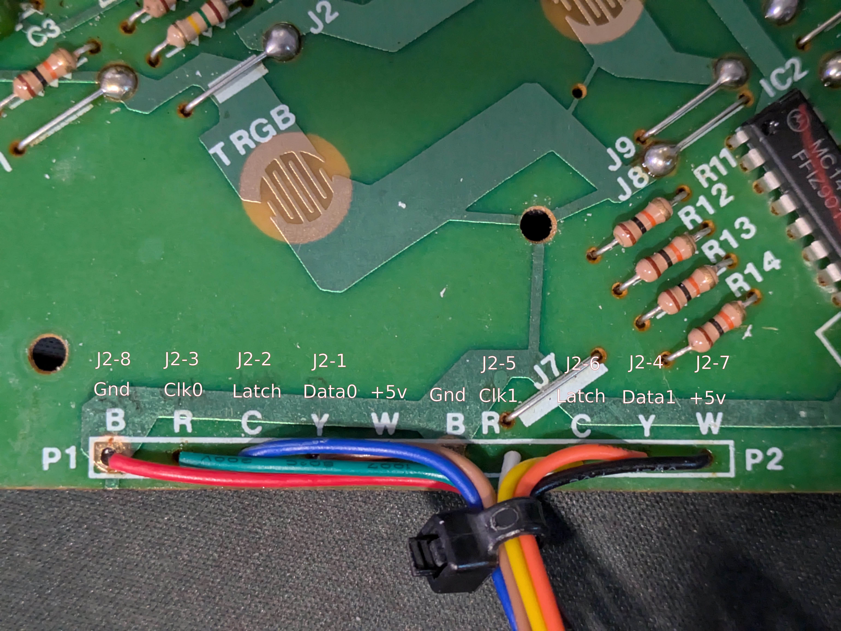
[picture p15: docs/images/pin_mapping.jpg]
Signal map on the controller board

Harness soldered along the board edge
All eight harness wires soldered

Route the wires clear of the joystick plate.
J2.

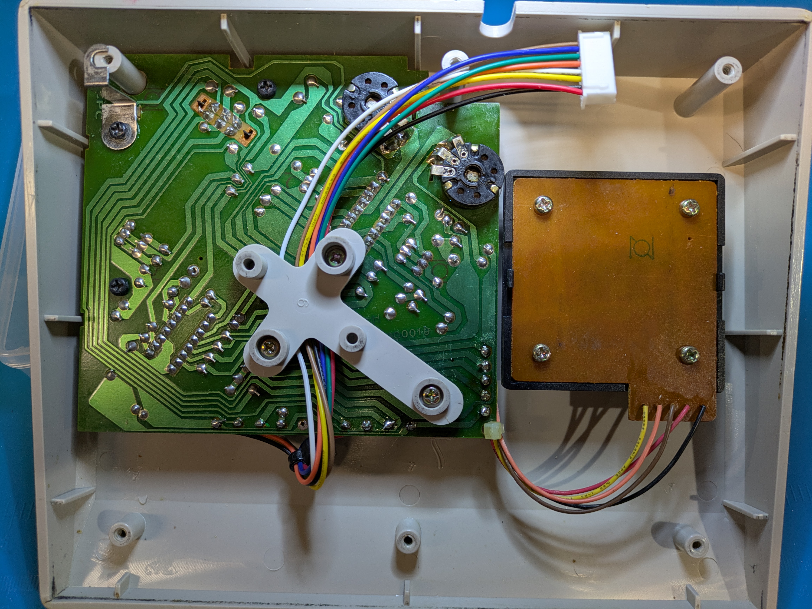
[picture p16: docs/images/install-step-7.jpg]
Harness terminated in the JST-XH plug


## 4. Place the board and battery

Set the battery in the open floor area and plug the harness into J2, with the board aligned so its
jack sits in the original cable hole.

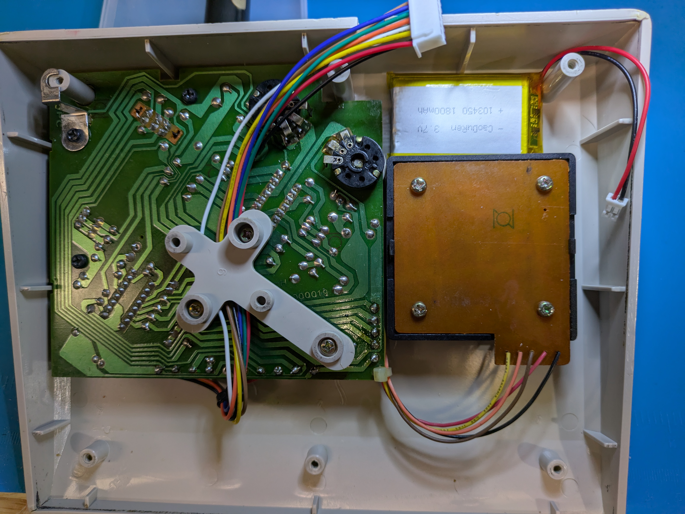
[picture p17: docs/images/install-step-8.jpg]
Battery placed in the case

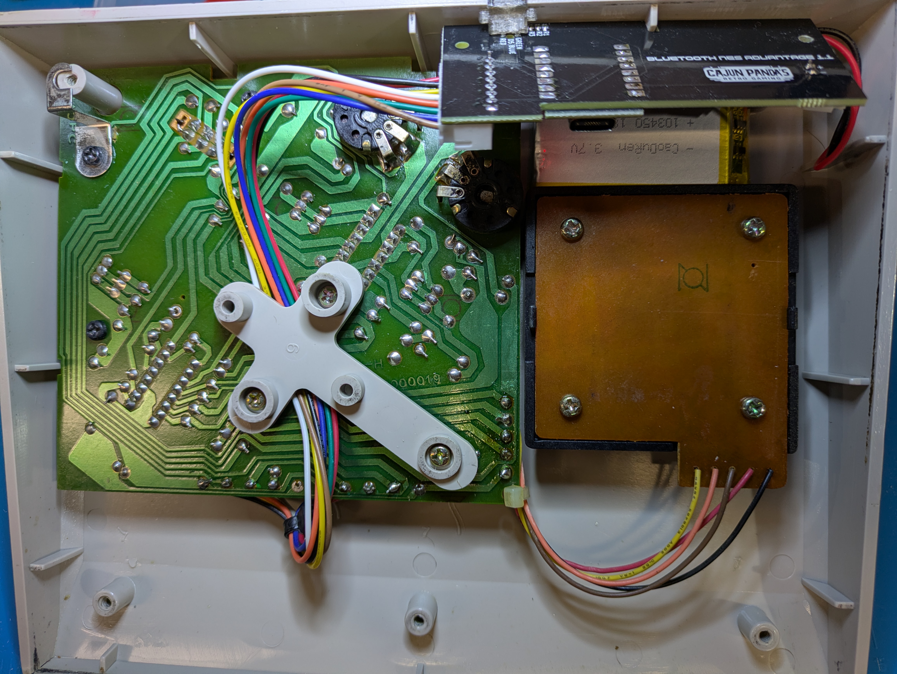
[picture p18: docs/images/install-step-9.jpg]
Board connected and seated at the cable hole


## 5. Connect the battery

Check polarity against the board's + and - silk marks first; there is no standard JST-PH polarity.

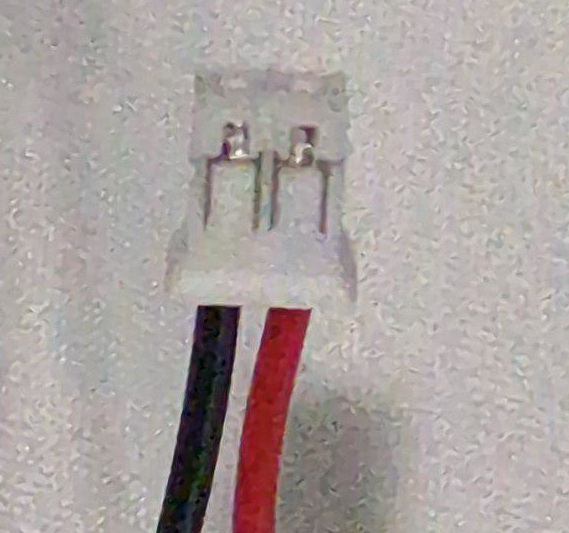
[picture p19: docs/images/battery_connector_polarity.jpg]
Battery connector polarity


## 6. Insulate and reassemble

Put insulating tape on the metal back plate before reassembling.

Back cover tape

## 7. Fit the DC jack plug

A 3D-printable plug fills the cable hole around the jack. Print it in transparent PLA so the status
LEDs show through. STL and FreeCAD source:
[`../hardware/bt-nes-advantage-jack-plug/`](../hardware/bt-nes-advantage-jack-plug/)

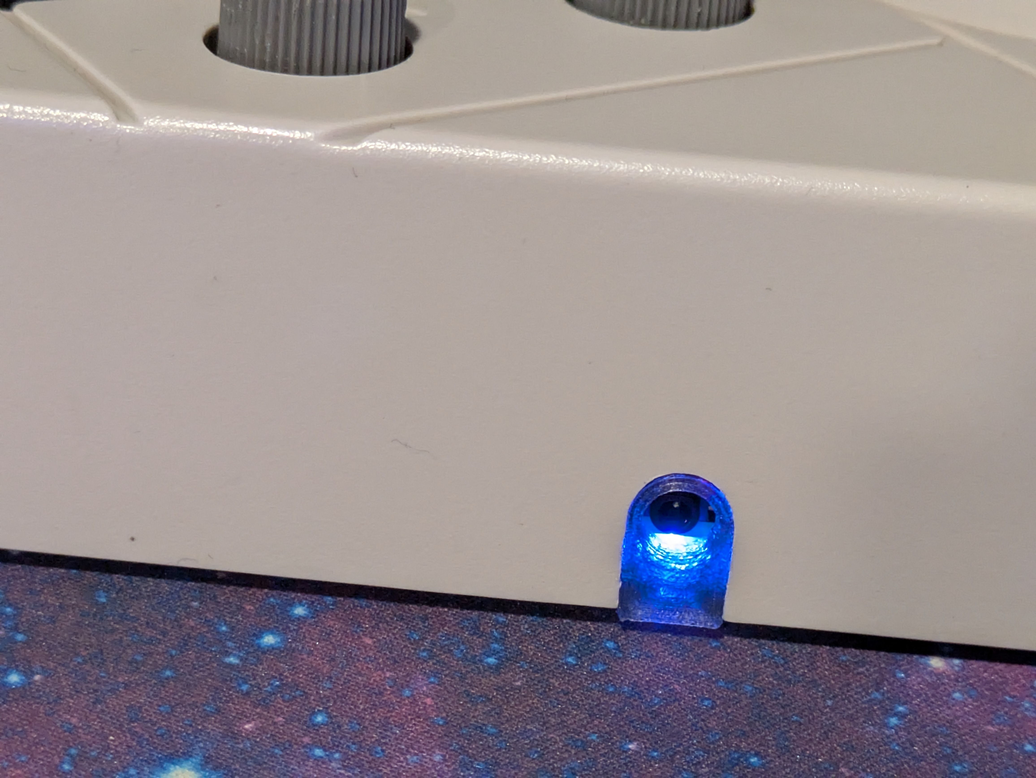
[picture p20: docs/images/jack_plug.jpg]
Jack plug

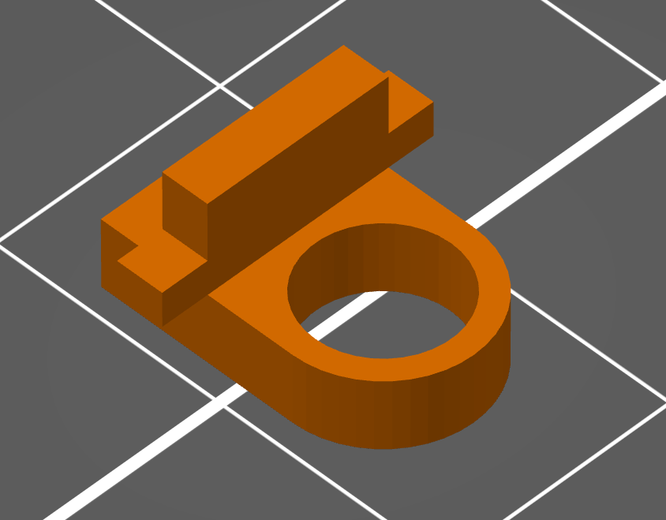
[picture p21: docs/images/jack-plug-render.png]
Jack plug render


## Done

Power on by holding Start, then pair. See [MANUAL.md](MANUAL.md) for pairing, gestures, and LEDs.

## Troubleshooting

If the board can't reach the controller it boots into config mode with the red LED blinking, and the
config page shows "No controller detected on J2". Common causes:

- A loose harness or a cold or bridged solder joint at J2 or on the controller board.
- A dirty player-select switch. If both players read as deselected the board sees no data; clean the
  switch contacts.
- The metal back plate shorting the J2 connector. Make sure it is insulated (step 6).

In the config page's controller tester, toggle the player-select slider: if the warning clears on
one side but not the other, that side's DATA/CLOCK/LATCH wiring is the problem.

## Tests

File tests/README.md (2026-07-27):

# tests/

Host-side tests for firmware logic that is worth checking without a board in hand. No hardware, no
ESP-IDF, no PlatformIO: a normal host compiler builds the code under test against stubs.

```bash
./tests/run.sh          # build and run everything; non-zero exit on failure
CXX=clang++ ./tests/run.sh
```

Build output lands in `tests/.build/` (gitignored).

## How the code under test gets here

The logic being tested is `static` inside `firmware/main/app_main.cpp` and sits behind ESP-IDF
headers, so `run.sh` lifts the relevant section straight out of that file and the test includes it.
The tests therefore run the shipped state machine rather than a transcription of it, which is the
whole point: edit `app_main.cpp` and the tests see the edit.

The section boundaries are the banner comments already in the source, not line numbers, so they
survive edits above them. If a marker is renamed or removed, `run.sh` fails loudly with the marker it
was looking for instead of testing an empty fragment. Renaming a banner comment means updating the
matching string in `run.sh`.

Anything the extracted section touches is stubbed in the test: a fake clock, the `bt::NesInput`
fields, the `settings::` constants it reads, and `ESP_LOGI`. A fake clock rather than real time keeps
window and pulse boundaries exact instead of timing-dependent.

## What is covered

`chords_test.cpp` covers the chord layer (Select as a shift key, see
[`../docs/FIRMWARE.md`](../docs/FIRMWARE.md)) across all three window modes:

- **Off**: Select is an ordinary button, held while held, and no chord fires.
- **Hold**: Minus withheld for the whole press and pulsed on release; a chord reached long after the
  press still works.
- **Bounded**: a chord inside the window fires and follows the hold; the window closing commits Minus
  so it can be held; a member arriving after the window does *not* chord; a tap shorter than the
  window still pulses on release.

Plus the edge cases the layer exists to get right: a direction already held when Select lands keeps
steering rather than chording, a member landing in the same poll as Select still chords, two taps
with a direction held do not produce a phantom chord, and re-pressing Select inside the release pulse
truncates it rather than leaking Minus into the new press.

Run `tests/.build/chords_test -v` to see the layer's own log lines interleaved with the scenarios.

## Adding a test

Add the `.cpp` next to this file, then in `run.sh` add an `extract` call for the section it needs and
a `run_case` line. Keep each test a plain `main()` returning non-zero on failure; there is no test
framework and nothing here needs one.

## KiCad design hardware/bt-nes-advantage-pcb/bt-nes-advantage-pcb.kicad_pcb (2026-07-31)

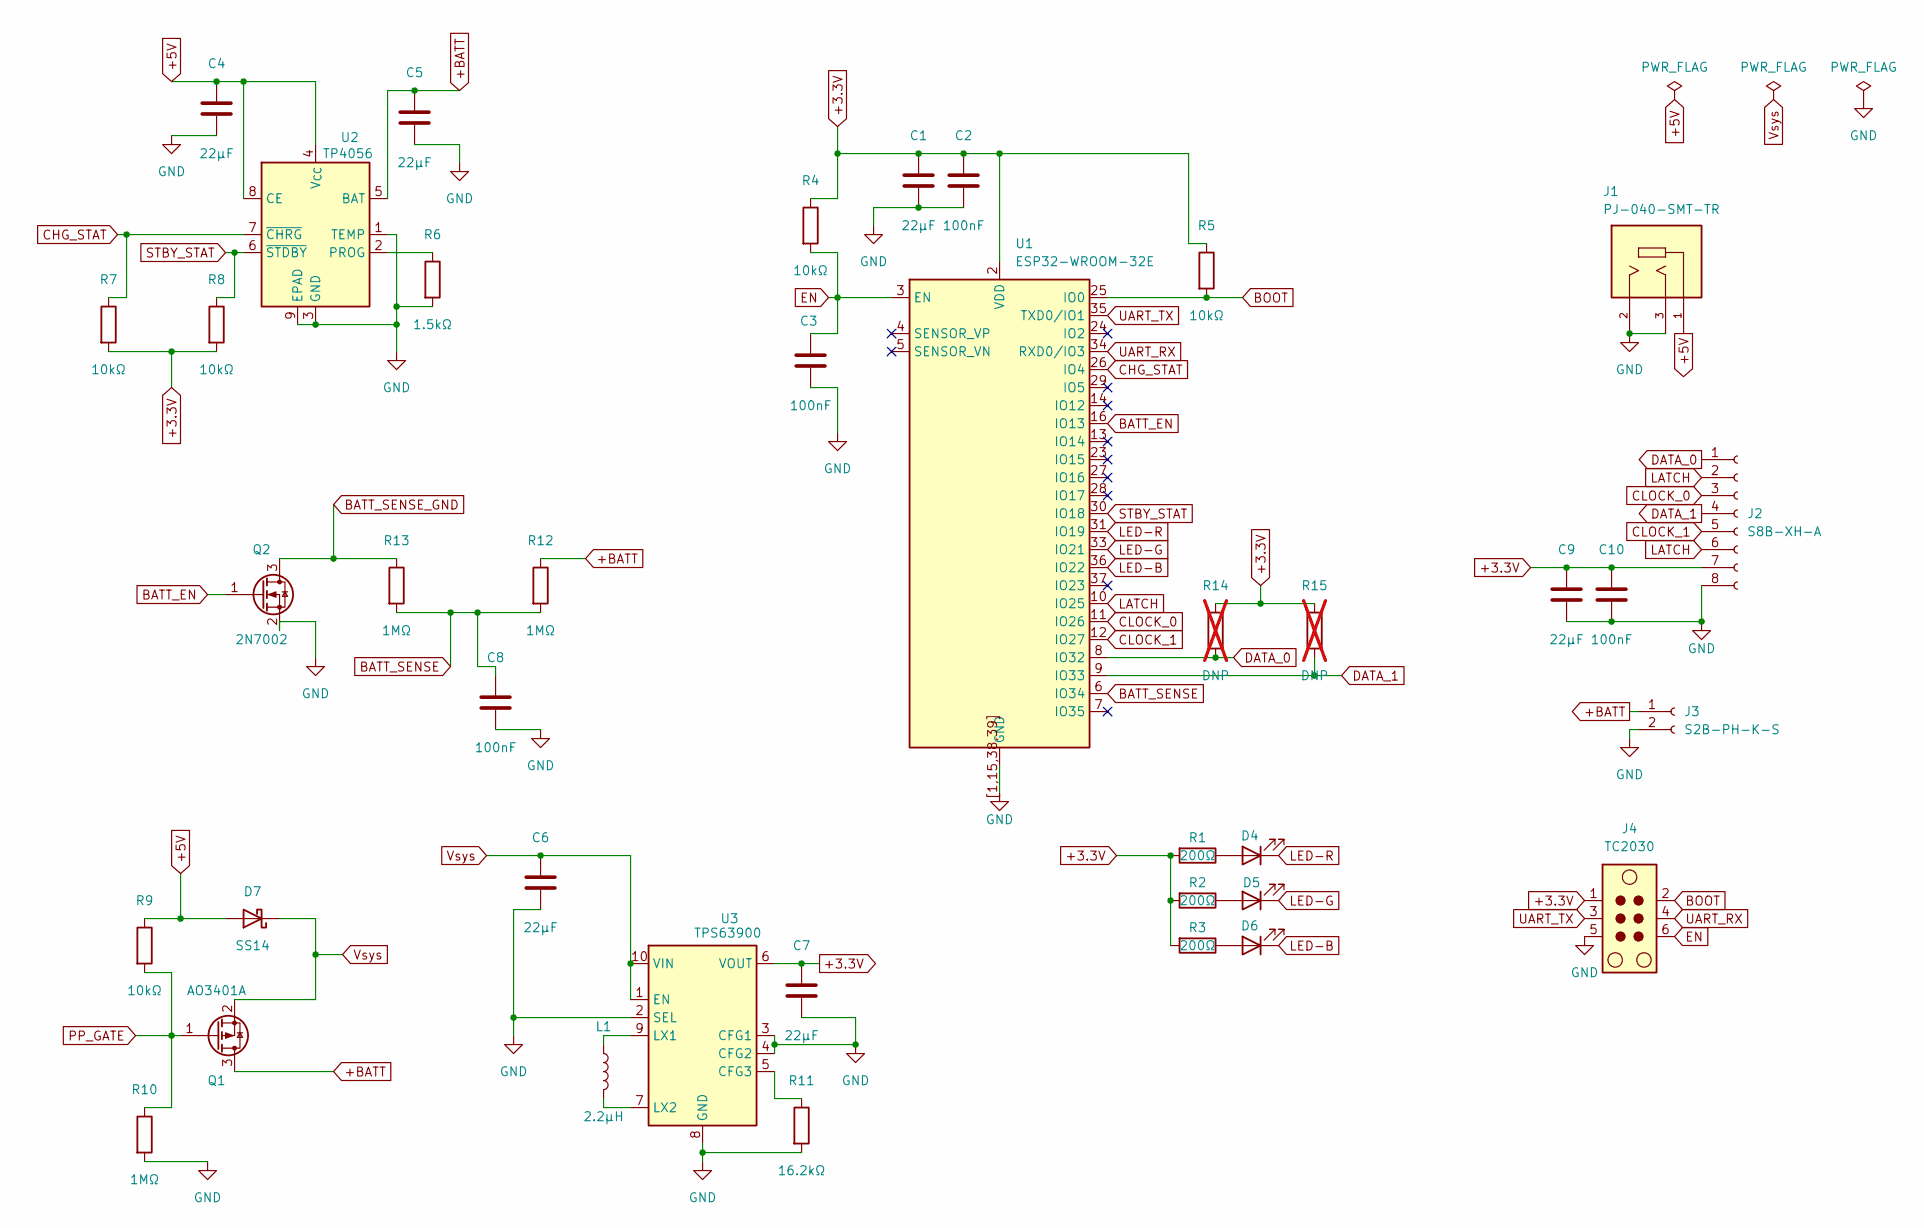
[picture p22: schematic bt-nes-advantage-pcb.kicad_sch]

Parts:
C1, C4, C5, C6, C7, C9: 22µF; C_0805_2012Metric_Pad1.18x1.45mm_HandSolder; MPN CL21A226KOQNNNE; LCSC C296720
C2, C3, C8, C10: 100nF; C_0603_1608Metric_Pad1.08x0.95mm_HandSolder; MPN CC0603KRX7R9BB104; LCSC C14663
D4: LTST-C193KRKT-5A; LED_0603_1608Metric_Pad1.05x0.95mm_HandSolder; MPN LTST-C193KRKT-5A; LCSC C157741
D5: LTST-C193KGKT-5A; LED_0603_1608Metric_Pad1.05x0.95mm_HandSolder; MPN LTST-C193KGKT-5A; LCSC C125102
D6: LTST-C193TBKT-5A; LED_0603_1608Metric_Pad1.05x0.95mm_HandSolder; MPN LTST-C193TBKT-5A; LCSC C125103
D7: SS14; D_SMA; MPN SS14; LCSC C2480
J1: PJ-040-SMT-TR; CUI_PJ-040-SMT-TR; MPN PJ-040-SMT-TR; Mouser Part Number 490-PJ-040-SMT-TR
J2: S8B-XH-A; JST_XH_S8B-XH-A_1x08_P2.50mm_Horizontal; MPN S8B-XH-A(LF)(SN); LCSC C157914
J3: S2B-PH-K-S; JST_PH_S2B-PH-K_1x02_P2.00mm_Horizontal; MPN S2B-PH-K-S(LF)(SN); LCSC C173752
J4: TC2030; Tag-Connect_TC2030-IDC-FP_2x03_P1.27mm_Vertical
L1: 2.2µH; L_Murata_DFE201610P; MPN DFE201610P-2R2M=P2; LCSC C237554
Q1: AO3401A; SOT-23; MPN AO3401A; LCSC C15127
Q2: 2N7002; SOT-23; MPN 2N7002; LCSC C8545
R1, R2, R3: 200Ω; R_0603_1608Metric_Pad0.98x0.95mm_HandSolder; MPN 0603WAF2000T5E; LCSC C8218
R4, R5, R7, R8, R9: 10kΩ; R_0603_1608Metric_Pad0.98x0.95mm_HandSolder; MPN 0603WAF1002T5E; LCSC C25804
R6: 1.5kΩ; R_0603_1608Metric_Pad0.98x0.95mm_HandSolder; MPN 0603WAF1501T5E; LCSC C22843
R10, R12, R13: 1MΩ; R_0603_1608Metric_Pad0.98x0.95mm_HandSolder; MPN 0603WAF1004T5E; LCSC C22935
R11: 16.2kΩ; R_0603_1608Metric_Pad0.98x0.95mm_HandSolder; MPN 0603WAF1622T5E; LCSC C22885
R14, R15: DNP; R_0603_1608Metric_Pad0.98x0.95mm_HandSolder; not fitted
U1: ESP32-WROOM-32E; MPN ESP32-WROOM-32E-N4; LCSC C701341
U2: TP4056; SOIC-8-1EP_3.9x4.9mm_P1.27mm_EP2.29x3mm_ThermalVias; MPN TP4056-42-ESOP8; LCSC C16581
U3: TPS63900; WSON-10-1EP_2.5x2.5mm_P0.5mm_EP1.2x2mm_ThermalVias; MPN TPS63900DSKR; LCSC C1518762

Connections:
+3.3V: C1.1, C2.1, C7.1, C9.1, C10.1, J2.7, J4.1, R1.2, R2.2, R3.2, R4.1, R5.1, R7.2, R8.2, R14.1, R15.1, U1.2 (VDD), U3.6 (VOUT)
+5V: C4.1, D7.2 (A), J1.1, R9.1, U2.4 (V_{CC}), U2.8 (CE)
+BATT: C5.1, J3.1, Q1.3 (D), R12.1, U2.5 (BAT)
BATT_EN: Q2.1 (G), U1.16 (IO13)
BATT_SENSE: C8.1, R12.2, R13.2, U1.6 (IO34)
BATT_SENSE_GND: Q2.3 (D), R13.1
BOOT: J4.2, R5.2, U1.25 (IO0)
CHG_STAT: R7.1, U1.26 (IO4), U2.7 (~CHRG)
CLOCK_0: J2.3, U1.11 (IO26)
CLOCK_1: J2.5, U1.12 (IO27)
DATA_0: J2.1, R14.2, U1.8 (IO32)
DATA_1: J2.4, R15.2, U1.9 (IO33)
EN: C3.1, J4.6, R4.2, U1.3 (EN)
GND: C1.2, C2.2, C3.2, C4.2, C5.2, C6.2, C7.2, C8.2, C9.2, C10.2, J1.2, J1.3, J2.8, J3.2, J4.5, Q2.2 (S), R6.2, R10.2, R11.2, U1.1 (GND), U1.15 (GND), U1.38 (GND), U1.39 (GND), U1.[1,15,38,39] (GND), U2.1 (TEMP), U2.3 (GND), U2.9 (EPAD), U3.2 (SEL), U3.3 (CFG1), U3.4 (CFG2), U3.8 (GND), U3.11 (GND)
LATCH: J2.2, J2.6, U1.10 (IO25)
LED-B: D6.1 (K), U1.36 (IO22)
LED-G: D5.1 (K), U1.33 (IO21)
LED-R: D4.1 (K), U1.31 (IO19)
unnamed: D4.2 (A), R1.1
unnamed: D5.2 (A), R2.1
unnamed: D6.2 (A), R3.1
unnamed: R6.1, U2.2 (PROG)
unnamed: R11.1, U3.5 (CFG3)
unnamed: L1.1, U3.9 (LX1)
unnamed: L1.2, U3.7 (LX2)
PP_GATE: Q1.1 (G), R9.2, R10.1
STBY_STAT: R8.1, U1.30 (IO18), U2.6 (~STDBY)
UART_RX: J4.4, U1.34 (RXD0/IO3)
UART_TX: J4.3, U1.35 (TXD0/IO1)
Vsys: C6.1, D7.1 (K), Q1.2 (S), U3.1 (EN), U3.10 (VIN)

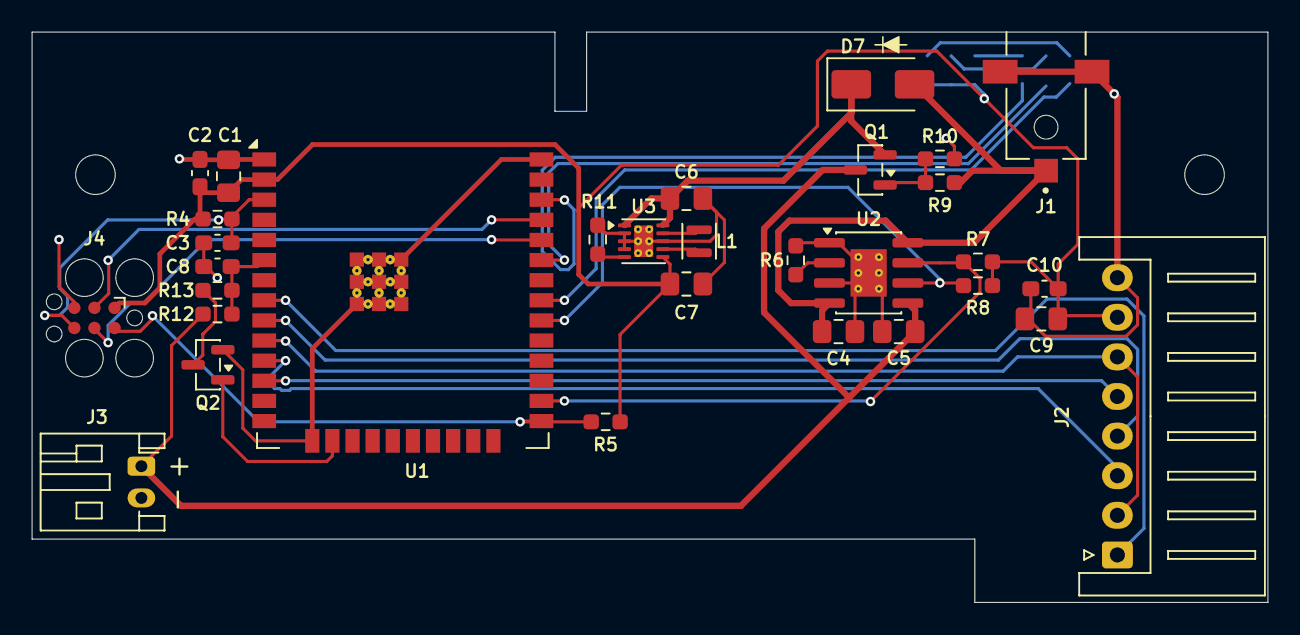
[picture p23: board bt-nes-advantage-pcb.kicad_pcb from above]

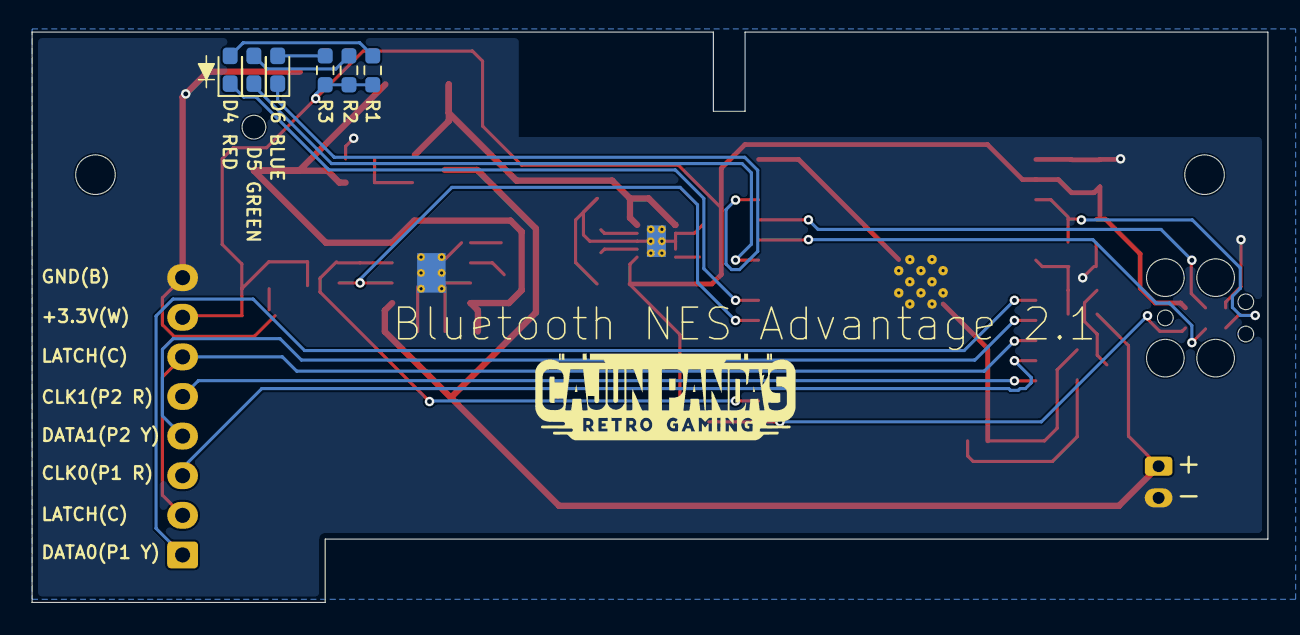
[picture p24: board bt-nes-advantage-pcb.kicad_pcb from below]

Board: 2 copper layers, 78.0 x 36.0 mm, 37 parts (6 on the bottom side), 30 nets.

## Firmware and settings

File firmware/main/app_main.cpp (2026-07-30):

// SPDX-License-Identifier: MIT
// Copyright 2026 Aaron Perkins

// Bluetooth NES Advantage firmware entry point.
//
// Default build (env `wroom32`): the gameplay firmware. It ties together dual-mode transport select
// (Classic Switch Pro / BLE), player select, button profiles, directional modes, hold-button
// gestures, LEDs, battery, and the deep-sleep / ULP-wake state machine, behind the transport-neutral
// bt:: API.

#include "freertos/FreeRTOS.h"
#include "freertos/task.h"
#include "esp_log.h"

#include <cstring>
#include <cstdint>
#include "esp_sleep.h"
#include "esp_attr.h"
#include "esp_timer.h"
#include "esp_system.h"
#include "driver/gpio.h"
#include "nvs_flash.h"

#include "board_config.h"
#include "board.hpp"
#include "settings.hpp"
#include "battery.hpp"
#include "power.hpp"
#include "nes_controller.hpp"
#include "bt_transport.hpp"
#include "bt_config.hpp"
#include "console.hpp"
#include "linklog.hpp"
#include "app_control.hpp"

static const char* TAG = "app";

// --- Timings (ms unless noted) -----------------------------------------------------------------
static constexpr int64_t kConnIdleTimeoutMs = 90'000;    // unconnected this long -> sleep
static constexpr int64_t kIdleTimeoutMs     = 300'000;   // no button activity this long -> sleep
static constexpr int64_t kGestureHoldMs     = 5'000;     // all hold-combos: 5 s
static constexpr int64_t kBatteryPollMs     = 1'000;

// --- Persisted across deep sleep (survives the reset that deep sleep performs) ------------------
RTC_DATA_ATTR static bool s_sleeping = false;
// One-shot request set by the A+B+Select gesture: the next boot enters BLE config/OTA mode, then a
// plain reboot (or an applied setting) returns to normal gameplay. This must survive esp_restart(),
// so it uses RTC_NOINIT_ATTR (RTC_DATA_ATTR is RE-INITIALIZED on a software reset, it only persists
// across deep-sleep wake). It's uninitialized on power-on, so we only honor it after a software
// reset (esp_restart) and clear it once read.
RTC_NOINIT_ATTR static uint32_t s_config_magic;
static constexpr uint32_t kConfigMagic = 0xC0FF1900;

// --- Globals -----------------------------------------------------------------------------------
static NESController* nes = nullptr;
static uint8_t  s_player  = 0;
static uint8_t  s_profile = 0;
static uint8_t  s_dirmode = 0;
static int64_t  s_last_connected_ms = 0;
static int64_t  s_last_battery_ms   = 0;
static bool     s_start_release_required = false;   // set on Start-wake; blocks instant re-sleep
static bool     s_led_auto = true;                  // false = console owns the LEDs (see app::set_led_auto)
static bool     s_sleep_requested = false;          // console `sleep`: enter deep sleep from the loop
static bool     s_sleep_inhibit = false;            // bench: suppress idle/disconnect auto-sleep
static uint8_t  s_raw_p1 = 0xFF, s_raw_p2 = 0xFF;   // last raw controller sample (for `diag`)
static bt::NesInput s_last_sent;                    // last snapshot handed to the transport
static bool     s_have_sent = false;                // false = force a send (nothing sent, or report zeroed)

static inline int64_t now_ms() { return esp_timer_get_time() / 1000; }

// --- LEDs (active-low) -------------------------------------------------------------------------
static void led_init() {
    gpio_config_t io = {};
    io.mode = GPIO_MODE_OUTPUT;
    io.pin_bit_mask = (1ULL << LED_RED) | (1ULL << LED_GREEN) | (1ULL << LED_BLUE);
    gpio_config(&io);
    gpio_set_level((gpio_num_t)LED_RED, 1);
    gpio_set_level((gpio_num_t)LED_GREEN, 1);
    gpio_set_level((gpio_num_t)LED_BLUE, 1);
}
static inline void led_set(int pin, bool on) { gpio_set_level((gpio_num_t)pin, on ? 0 : 1); }

// Blink an LED `count` times (blocking) to confirm a gesture selection.
static void led_blink(int pin, uint8_t count) {
    led_set(pin, false);
    vTaskDelay(pdMS_TO_TICKS(400));
    for (uint8_t i = 0; i < count; i++) {
        led_set(pin, true);  vTaskDelay(pdMS_TO_TICKS(250));
        led_set(pin, false); vTaskDelay(pdMS_TO_TICKS(250));
    }
}

// --- Sleep -------------------------------------------------------------------------------------
static void enter_sleep() {
    ESP_LOGI(TAG, "entering deep sleep (ULP polls the controller; press Start to wake)");
    // The unconnected-idle sleep arrives well before the re-page budget runs out, so this is where
    // a boot that never connected ends. Without the flush it leaves no summary behind once the
    // battery comes out. The RTC ring itself survives deep sleep.
    linklog::persist();
    led_set(LED_RED, false); led_set(LED_GREEN, false); led_set(LED_BLUE, false);

    // Start both sleeps AND wakes the device, so the ULP baseline must be captured with Start
    // released. If we arm the ULP while the sleep-hold is still down, that held state reads as a
    // change on the first post-sleep poll and wakes us right back up. Wait for Start to be released
    // (debounced) before arming, with a safety cap so a stuck/garbage read can't hang here forever.
    // (When called from the idle/disconnect timeouts Start isn't held, so this returns immediately.)
    int64_t deadline = now_ms() + 3000;
    int released = 0;
    while (now_ms() < deadline) {
        nes->read();
        released = nes->getButtonState(s_player, NESController::BUTTON_START) ? 0 : released + 1;
        if (released >= 5) break;       // ~50ms continuously released
        vTaskDelay(pdMS_TO_TICKS(10));
    }
    if (released < 5) ESP_LOGW(TAG, "Start still held at sleep; arming anyway");

    s_sleeping = true;
    power::ulp_load();                 // arm the ULP 4021 poll (wake-on-button-change)
    vTaskDelay(pdMS_TO_TICKS(120));    // let the serial log flush
    power::deep_sleep();               // does not return; SoC reboots on the next ULP wake
}

// On boot after a deep sleep, decide whether to wake fully (Start pressed) or go back to sleep.
// Returns true if we should continue with a full boot.
static bool handle_wake() {
    if (!s_sleeping) return true;      // cold boot / normal start
    esp_sleep_wakeup_cause_t cause = esp_sleep_get_wakeup_cause();
    bool start_held = power::button_pressed_in_last_read(NESController::BUTTON_START);

    // Charger inserted while asleep (PCB 2.1+, where CHG_STAT is on an RTC pin). Boot fully so the
    // charge indication runs: external_power() then holds the device awake, check_timers() keeps
    // the idle timers reset, and the green LED blinks while charging and goes solid at full. Once
    // the charger comes out the normal idle timeout takes over and puts it back to sleep.
    //
    // Keyed on the pin as well as the wake cause: the ULP and ext1 are both armed, so a button
    // change and a charger insert can land on the same wake, and esp_sleep_get_wakeup_cause()
    // only reports one of the two. Reading CHG_STAT directly cannot miss it.
    if (cause == ESP_SLEEP_WAKEUP_EXT1 || (board::chg_wake_capable() && battery::is_charging())) {
        ESP_LOGI(TAG, "charger inserted -> powering on for charge indication");
        s_sleeping = false;
        power::release_after_wake();
        return true;
    }

    if (cause == ESP_SLEEP_WAKEUP_ULP && start_held) {
        ESP_LOGI(TAG, "ULP wake + Start held -> powering on");
        s_sleeping = false;
        s_start_release_required = true;     // don't let the same hold immediately re-sleep
        power::release_after_wake();         // hand the NES pins back to the normal gpio driver
        return true;
    }
    ESP_LOGI(TAG, "wake without Start (cause=%d) -> back to sleep", cause);
    power::ulp_load();
    vTaskDelay(pdMS_TO_TICKS(120));
    power::deep_sleep();
    return false;                      // unreachable
}

// --- Player select -----------------------------------------------------------------------------
static void chords_reset();            // defined with the chord layer below

static void on_player_change(uint8_t newPlayer) {
    bt::clear_input();                 // zero the previous player's report before switching
    s_player = newPlayer;
    chords_reset();                    // shift latch + pulse belonged to the old player
    s_have_sent = false;               // clear_input zeroed the report; force the resend
    ESP_LOGI(TAG, "player select -> P%d", s_player + 1);
}

// --- Profiles / directional modes --------------------------------------------------------------
static void cycle_profile() {
    s_profile = (s_profile + 1) % bt::num_profiles();
    settings::set_profile(s_profile);
    ESP_LOGI(TAG, "profile -> %u (%s)", s_profile + 1, bt::profile_name(s_profile));
    led_blink(LED_RED, s_profile + 1);
}
static void cycle_directional_mode() {
    s_dirmode = (s_dirmode + 1) % bt::num_directional_modes();
    settings::set_directional_mode(s_dirmode);
    ESP_LOGI(TAG, "directional mode -> %u (%s)", s_dirmode + 1, bt::directional_mode_name(s_dirmode));
    led_blink(LED_RED, s_dirmode + 1);
}
static void enter_config_mode() {
    ESP_LOGW(TAG, "entering BLE config/OTA mode; rebooting");
    // Persist here, not after the reboot: this is the boot whose reconnect failed, and the gesture
    // that reads the log out is what ends it. On the far side of esp_restart the summary describes
    // config mode instead, all zeroes, and burns a history slot saying nothing.
    linklog::event(linklog::EV_CONFIG);
    linklog::persist();
    led_blink(LED_BLUE, 3);
    s_config_magic = kConfigMagic;   // survives esp_restart (RTC_NOINIT); consumed on next boot
    vTaskDelay(pdMS_TO_TICKS(200));
    esp_restart();
}
static void toggle_transport() {
    uint8_t next = (settings::transport() + 1) % bt::TRANSPORT_COUNT;
    settings::set_transport(next);
    ESP_LOGW(TAG, "transport -> %s; rebooting", bt::transport_name((bt::Transport)next));
    led_blink(LED_BLUE, next + 1);
    vTaskDelay(pdMS_TO_TICKS(200));
    esp_restart();
}

// --- Chords: Select as a shift key -------------------------------------------------------------
// Select + Start -> Home, Up -> ZL+ZR, Down -> Capture, Left -> ZL, Right -> ZR. Output follows the
// hold; a chord suppresses its members' normal roles. Select alone is still Minus.
//
// A/B are not chord members: the Turbo dials pulse those lines in hardware. Slow motion pulses Start
// the same way, so it must be off to use Select+Start (see docs/MANUAL.md).
static constexpr int64_t kMinusPulseMs = 80;   // >= 10 Switch polls (8 ms apart); still reads as a tap

enum ChordBit : uint8_t {   // chord members, in NES poll order after Select
    CH_START = 0x01, CH_UP = 0x02, CH_DOWN = 0x04, CH_LEFT = 0x08, CH_RIGHT = 0x10,
};

static bool    s_shift_armed = false;       // Select is down
static uint8_t s_shift_passthru = 0;        // members already held when Select landed; not chordable
static bool    s_chord_fired = false;       // a chord formed during this Select press
static uint8_t s_chord_active = 0;          // members currently shifted (for the log edge)
static bool    s_minus_committed = false;   // window closed with no chord: Minus is live and follows the hold
static int64_t s_shift_deadline = 0;        // now_ms() past this and the window is closed
static int64_t s_minus_pulse_until = 0;

// Window length for this boot, read once from NVS for the active transport (see settings.hpp).
// Cached because apply_chords runs every 2 ms poll and NVS reads are not free.
static uint16_t s_chord_window = settings::kChordOff;

// Button history, not chord state: chords_reset() must NOT clear it, or the next Select press reads
// an already-held direction as fresh and chords it (hold Right, tap Select twice -> phantom ZR).
static uint8_t s_prev_members = 0;

static void chords_reset() {
    s_shift_armed = false;
    s_shift_passthru = 0;
    s_chord_fired = false;
    s_chord_active = 0;
    s_minus_committed = false;
    s_shift_deadline = 0;
    s_minus_pulse_until = 0;
}

static const char* chord_name(uint8_t active) {
    switch (active) {
    case CH_START: return "Home";
    case CH_UP:    return "ZL+ZR";
    case CH_DOWN:  return "Capture";
    case CH_LEFT:  return "ZL";
    case CH_RIGHT: return "ZR";
    default:       return "multiple";
    }
}
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
extern "C" void app_main(void) {
    esp_err_t err = nvs_flash_init();
    if (err == ESP_ERR_NVS_NO_FREE_PAGES || err == ESP_ERR_NVS_NEW_VERSION_FOUND) {
        ESP_ERROR_CHECK(nvs_flash_erase());
        ESP_ERROR_CHECK(nvs_flash_init());
    }

    // Before handle_wake(): the sleep path needs to know whether this board can wake on the
    // charger, and before battery::init(), which configures the pin the probe resolves.
    board::init();

    if (!handle_wake()) return;          // went back to sleep (does not return in practice)

    ESP_LOGI(TAG, "Bluetooth NES Advantage, gameplay firmware");
    settings::init();
    // Ahead of the config-mode branch: the log is read out from config mode, so the recorder runs
    // on that boot too.
    linklog::init(settings::transport());

    // BLE config/OTA mode: the A+B+Select gesture armed s_config_magic and rebooted. Honor it only
    // on a software reset (so power-on garbage in the uninitialized RTC var can't trigger it), and
    // clear it immediately so it's one-shot, the next plain reboot returns to gameplay. config::run()
    // brings up BLE only and never returns (it reboots on apply/forget/OTA-done or an idle timeout).
    bool enter_config = (esp_reset_reason() == ESP_RST_SW && s_config_magic == kConfigMagic);
    ESP_LOGI(TAG, "boot: reset_reason=%d, config %s", esp_reset_reason(),
             enter_config ? "ARMED -> entering config/OTA mode" : "not requested");
    s_config_magic = 0;
    if (enter_config) {
        led_init();
        config::run();               // summary already written by enter_config_mode(), pre-reboot
    }

    settings::apply_bt_identity();       // rotate the BT MAC per identity generation (before BT init)
    battery::init();
    led_init();

    nes = new NESController(NES_CLK_P1, NES_CLK_P2, NES_LATCH, NES_DATA_P1, NES_DATA_P2);
    nes->begin();

    // Wiring check first: a disconnected controller reads as all-buttons-held, which oscillates
    // player-select and trips the Select+Start transport gesture into a reboot loop. If nothing is
    // driving either DATA line, boot into BLE config/OTA mode instead, where the web page's live
    // tester shows the fault and can reflash. enter_config_mode() reboots (does not return).
    if (nes->diagnose() == NESController::NES_NO_SIGNAL) {
        ESP_LOGW(TAG, "no NES Advantage detected on J2 (both data lines idle-high) -> config mode");
        enter_config_mode();
    }

    nes->read();
    s_player = nes->getPlayerSelection();
    nes->setPlayerSelectionCallback(on_player_change);

    bt::Transport transport = (bt::Transport)settings::transport();
    ESP_LOGI(TAG, "active player P%d, transport %s, identity gen %u",
             s_player + 1, bt::transport_name(transport), settings::identity_generation());
    bt::init(transport);

    // Load + clamp persisted profile / directional mode to the active transport's tables.
    s_profile = settings::profile();
    if (s_profile >= bt::num_profiles()) s_profile = 0;
    s_dirmode = settings::directional_mode();
    if (s_dirmode >= bt::num_directional_modes()) s_dirmode = 0;
    ESP_LOGI(TAG, "profile %u (%s), directional mode %u (%s)",
             s_profile + 1, bt::profile_name(s_profile),
             s_dirmode + 1, bt::directional_mode_name(s_dirmode));

    // Chord window for this transport. Read once: apply_chords runs every poll.
    s_chord_window = settings::chord_window_ms(transport);
    if (s_chord_window == settings::kChordOff)
        ESP_LOGI(TAG, "chord window: off (Select is a plain button)");
    else if (s_chord_window == settings::kChordHold)
        ESP_LOGI(TAG, "chord window: hold (Minus withheld until release)");
    else
        ESP_LOGI(TAG, "chord window: %u ms", s_chord_window);

    s_last_connected_ms = now_ms();
    s_last_battery_ms   = now_ms();

    console_start();                     // UART REPL for bench + automated testing (serial_proxy send)

    char prev_raw[24] = "";
    TickType_t last_log = 0;
    while (true) {
        nes->read();

        // Publish the raw sample for the `diag` console command (bit7=A..bit0=R, 1=pressed;
        // 0xFF = deselected/disconnected sentinel).
        { uint8_t p1 = 0, p2 = 0;
          for (int i = 0; i < 8; i++) {
              p1 = (p1 << 1) | (nes->getButtonState(0, i) ? 1 : 0);
              p2 = (p2 << 1) | (nes->getButtonState(1, i) ? 1 : 0);
          }
          s_raw_p1 = p1; s_raw_p2 = p2; }

        // Gate the send on the resolved snapshot, not stateChanged(): the chord layer breaks the 1:1
        // between the two. The Minus pulse ends on a timer with no button moving, and a chord changes
        // what a held button means without the raw state moving.
        bt::NesInput in = read_input(s_player);
        apply_chords(in);
        if (!s_have_sent || !same_input(in, s_last_sent)) {
            bt::set_input(in, s_profile, s_dirmode);
            s_last_sent = in;
            s_have_sent = true;
        }

        if (nes->stateChanged(0) || nes->stateChanged(1)) {
            // Unified controller log: both raw lines (bit order A B Sel Sta U D L R) plus the active
            // player. Rate-limited because a flickering controller otherwise spams UART and can
            // starve the BT task. A deselected line reads all '1' (the player-select sentinel).
            char r0[9], r1[9];
            for (int i = 0; i < 8; i++) { r0[i] = nes->getButtonState(0, i) ? '1' : '0';
                                          r1[i] = nes->getButtonState(1, i) ? '1' : '0'; }
            r0[8] = r1[8] = '\0';
            char line[24];
            snprintf(line, sizeof(line), "%s %s P%d", r0, r1, nes->getPlayerSelection() + 1);
            if (strcmp(line, prev_raw) != 0 && (xTaskGetTickCount() - last_log) >= pdMS_TO_TICKS(50)) {
                ESP_LOGI(TAG, "RAW P1=%s P2=%s sel=P%d", r0, r1, nes->getPlayerSelection() + 1);
                strcpy(prev_raw, line);
                last_log = xTaskGetTickCount();
            }
        }

        if (s_sleep_requested) { s_sleep_requested = false; enter_sleep(); }  // console `sleep`

        check_gestures();
        update_leds();
        check_timers();
        // Re-poll the 4021 every ~2 ms (needs CONFIG_FREERTOS_HZ=1000; see sdkconfig.defaults). The
        // read is ~0.4 ms at the default 80 MHz, so the loop is ~80% idle and leaves the BT task
        // plenty of CPU, and keeps press-to-sample latency near ~1 ms on average. The change-gated
        // log above (50 ms rate-limit) still protects the UART from a flickering controller.
        vTaskDelay(pdMS_TO_TICKS(2));
    }
}

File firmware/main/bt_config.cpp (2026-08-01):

// SPDX-License-Identifier: MIT
// Copyright 2026 Aaron Perkins

// BLE configuration + OTA service. Brings up Bluedroid in BLE-only mode and serves a small custom
// GATT service so a browser (Web Bluetooth, see ../../web/) can read/change settings and flash
// new firmware over the air. One radio at a time: Classic is released; this never runs alongside a
// gameplay transport. Open GATT (no bonding) so the web page connects without pairing.
//
// GATT contract, keep in lockstep with web/index.html:
//   service  5f1d0000-7c5a-4e2a-9b6e-2a8f3c9d1e00
//   INFO     5f1d0001  read + notify   : JSON {name,fw,build,slot,batt,wiring,ident,transport,
//                                              profile,dirmode,linklog,chordwin[2],profiles[2][],
//                                              dirmodes[2][]}
//   CMD      5f1d0002  write           : JSON {transport|profile|dirmode|chordwin:int}
//                                        or {action:"reboot|forget"}
//     chordwin applies to whichever transport is stored when the write lands, so a client changing
//     both must write transport first (web/index.html does, in one apply batch). Chords are
//     Classic-only: chordwin[TRANSPORT_BLE] always reads 0 and writes against BLE are ignored.
//   OTACTL   5f1d0003  write + notify  : control [op,...] / status [code,...]
//   OTADATA  5f1d0004  write-no-resp   : raw firmware chunks
//   INPUT    5f1d0005  read + notify   : live controller frame (7 bytes, see input_frame below)
//   LOG      5f1d0006  notify          : device console/log stream (ESP_LOG tee, UTF-8 bytes)
//   CONSOLE  5f1d0007  write           : console command line (UTF-8, no newline); output on LOG
//
// OTA control opcodes (client->dev): 0x01 BEGIN [u32 size][u32 crc], 0x02 END, 0x03 ABORT.
// OTA status codes (dev->client):    0x10 READY [u32 chunk][u32 window], 0x11 ACK [u32 received],
//                                     0x12 DONE, 0x1f ERROR [u8 code][msg].
//
// INPUT frame (little-endian, notified on change + ~500 ms heartbeat):
//   [0] tag 0x01  [1] player (0=P1,1=P2, the hardware select switch)
//   [2] active player's buttons, active-high bitmask (bit0=A,1=B,2=Select,3=Start,4=Up,5=Down,
//       6=Left,7=Right)  [3] turbo A rate Hz  [4] turbo B rate Hz
//   [5] battery percent (0..100, 0xff=absent)  [6] battery flags (bit0 charging,1 full,2 external)

#include "bt_config.hpp"
#include "settings.hpp"
#include "battery.hpp"
#include "board_config.h"
#include "bt_transport.hpp"
#include "linklog.hpp"
#include "nes_controller.hpp"

#include <cstring>
#include <cstdio>
#include <cstdarg>
#include <cstdlib>

#include "freertos/FreeRTOS.h"
#include "freertos/task.h"
#include "esp_log.h"
#include "esp_system.h"
#include "esp_timer.h"
#include "esp_mac.h"
#include "driver/gpio.h"

#include "esp_bt.h"
#include "esp_bt_main.h"
#include "esp_gap_ble_api.h"
#include "esp_gatts_api.h"
#include "esp_gatt_common_api.h"

#include "esp_ota_ops.h"
#include "esp_partition.h"
#include "esp_rom_crc.h"
#include "cJSON.h"

#define FW_VERSION "2.5.0"

static const char* TAG = "bt_config";

namespace {

// --- 128-bit UUIDs (little-endian byte order; index 12 selects the characteristic) -------------
#define CFG_UUID128(dd) {0x00,0x1e,0x9d,0x3c,0x8f,0x2a,0x6e,0x9b,0x2a,0x4e,0x5a,0x7c,(dd),0x00,0x1d,0x5f}
uint8_t uuid_svc[16]     = CFG_UUID128(0x00);
uint8_t uuid_info[16]    = CFG_UUID128(0x01);
uint8_t uuid_cmd[16]     = CFG_UUID128(0x02);
uint8_t uuid_otactl[16]  = CFG_UUID128(0x03);
uint8_t uuid_otadata[16] = CFG_UUID128(0x04);
uint8_t uuid_input[16]   = CFG_UUID128(0x05);
uint8_t uuid_log[16]     = CFG_UUID128(0x06);
uint8_t uuid_console[16] = CFG_UUID128(0x07);

// --- OTA protocol constants --------------------------------------------------------------------
constexpr uint8_t OP_BEGIN = 0x01, OP_END = 0x02, OP_ABORT = 0x03;
constexpr uint8_t ST_READY = 0x10, ST_ACK = 0x11, ST_DONE = 0x12, ST_ERROR = 0x1f;
constexpr uint32_t OTA_WINDOW   = 8192;   // bytes the client may send before an ACK
constexpr uint32_t OTA_CHUNK_MAX = 500;   // capped per-write payload (also bounded by MTU)

// --- GATT attribute table indices --------------------------------------------------------------
enum {
    IDX_SVC,
    IDX_INFO_CHAR, IDX_INFO_VAL, IDX_INFO_CCC,
    IDX_CMD_CHAR,  IDX_CMD_VAL,
    IDX_OTACTL_CHAR, IDX_OTACTL_VAL, IDX_OTACTL_CCC,
    IDX_OTADATA_CHAR, IDX_OTADATA_VAL,
    IDX_INPUT_CHAR, IDX_INPUT_VAL, IDX_INPUT_CCC,
    IDX_LOG_CHAR, IDX_LOG_VAL, IDX_LOG_CCC,
    IDX_CONSOLE_CHAR, IDX_CONSOLE_VAL,
    IDX_NB,
};
uint16_t s_handles[IDX_NB] = {0};

// --- runtime state -----------------------------------------------------------------------------
esp_gatt_if_t s_gatts_if = ESP_GATT_IF_NONE;
uint16_t s_conn_id = 0xffff;
bool     s_connected = false;
uint16_t s_mtu = 23;
int64_t  s_last_activity_ms = 0;
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

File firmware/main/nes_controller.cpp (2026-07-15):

// SPDX-License-Identifier: MIT
// Copyright 2026 Aaron Perkins

#include "nes_controller.hpp"
#include "esp_timer.h"
#include "esp_rom_sys.h"          // esp_rom_delay_us
#include "freertos/FreeRTOS.h"
#include "freertos/task.h"

static inline int64_t now_ms() { return esp_timer_get_time() / 1000; }

NESController::NESController(gpio_num_t clkPin1, gpio_num_t clkPin2, gpio_num_t latchPin,
                            gpio_num_t dataPin1, gpio_num_t dataPin2)
    : _clk1(clkPin1), _clk2(clkPin2), _latch(latchPin), _data1(dataPin1), _data2(dataPin2),
      _stateChanged{false, false}, _playerSelection(0), _lastActivityMs(0), _cb(nullptr) {
    for (int p = 0; p < 2; p++)
        for (int b = 0; b < 8; b++)
            _buttonState[p][b] = _prevButtonState[p][b] = false;
}

void NESController::begin() {
    gpio_config_t out = {};
    out.mode = GPIO_MODE_OUTPUT;
    out.pin_bit_mask = (1ULL << _clk1) | (1ULL << _clk2) | (1ULL << _latch);
    gpio_config(&out);

    gpio_config_t in = {};
    in.mode = GPIO_MODE_INPUT;
    // Pull-DOWN, not pull-up: the CD4021 push-pull output drives the selected line correctly either
    // way, but a deselected (high-Z) line must read LOW so it shifts out all-1s (active-low invert),
    // the "all-true" player-select sentinel. The deep-sleep ULP path uses pull-UP instead (opposite
    // need; see power.cpp config_rtc_gpio).
    in.pull_down_en = GPIO_PULLDOWN_ENABLE;
    in.pin_bit_mask = (1ULL << _data1) | (1ULL << _data2);
    gpio_config(&in);

    gpio_set_level(_latch, 0);
    gpio_set_level(_clk1, 0);
    gpio_set_level(_clk2, 0);
    _lastActivityMs = now_ms();
}

void NESController::read() {
    _stateChanged[0] = _stateChanged[1] = false;

    // Latch current button states (CD4021 parallel load; min ~12 us)
    gpio_set_level(_latch, 1);
    esp_rom_delay_us(12);
    gpio_set_level(_latch, 0);

    // Clock out all 8 buttons (active-low, invert)
    for (int i = 0; i < 8; i++) {
        _buttonState[0][i] = !gpio_get_level(_data1);
        _buttonState[1][i] = !gpio_get_level(_data2);

        gpio_set_level(_clk1, 1);
        gpio_set_level(_clk2, 1);
        esp_rom_delay_us(6);
        gpio_set_level(_clk1, 0);
        gpio_set_level(_clk2, 0);
        esp_rom_delay_us(6);
    }

    // Detect changes
    for (int i = 0; i < 8; i++) {
        if (_buttonState[0][i] != _prevButtonState[0][i]) {
            _stateChanged[0] = true;
            _prevButtonState[0][i] = _buttonState[0][i];
        }
        if (_buttonState[1][i] != _prevButtonState[1][i]) {
            _stateChanged[1] = true;
            _prevButtonState[1][i] = _buttonState[1][i];
        }
    }

    // Player-select switch: the deselected player's line reads all-8-high.
    uint8_t previous = _playerSelection;
    if (allTrue(_buttonState[0], 8) && _playerSelection != 1) {
        _playerSelection = 1;                  // P2 selected
    } else if (allTrue(_buttonState[1], 8) && _playerSelection != 0) {
        _playerSelection = 0;                  // P1 selected
    }
    if (_playerSelection != previous) {
        vTaskDelay(pdMS_TO_TICKS(100));        // debounce the switch
        if (_cb) _cb(_playerSelection);
    }

    if (_stateChanged[0] || _stateChanged[1]) _lastActivityMs = now_ms();
}

void NESController::sampleRaw(uint8_t& p1, uint8_t& p2) const {
    p1 = p2 = 0;
    gpio_set_level(_latch, 1);
    esp_rom_delay_us(12);
    gpio_set_level(_latch, 0);
    for (int i = 0; i < 8; i++) {
        p1 = (p1 << 1) | (gpio_get_level(_data1) ? 0 : 1);   // active-low: line low = pressed
        p2 = (p2 << 1) | (gpio_get_level(_data2) ? 0 : 1);
        gpio_set_level(_clk1, 1);
        gpio_set_level(_clk2, 1);
        esp_rom_delay_us(6);
        gpio_set_level(_clk1, 0);
        gpio_set_level(_clk2, 0);
        esp_rom_delay_us(6);
    }
}

NESController::ControllerState NESController::diagnose(int samples) const {
    bool p1live = false, p2live = false;
    for (int i = 0; i < samples; i++) {
        uint8_t a, b;
        sampleRaw(a, b);
        if (a != 0xFF) p1live = true;
        if (b != 0xFF) p2live = true;
    }
    return classify(p1live ? 0x00 : 0xFF, p2live ? 0x00 : 0xFF);
}

bool NESController::stateChanged(uint8_t player) const {
    return (player < 2) ? _stateChanged[player] : false;
}

bool NESController::getButtonState(uint8_t player, uint8_t button) const {
    return (player < 2 && button < 8) ? _buttonState[player][button] : false;
}

void NESController::resetLastActivity() { _lastActivityMs = now_ms(); }

uint8_t NESController::getHatDirection(uint8_t player) const {
    if (player >= 2) return 0;
    const bool* b = _buttonState[player];
    if (b[BUTTON_UP] && b[BUTTON_RIGHT])    return 2;
    if (b[BUTTON_RIGHT] && b[BUTTON_DOWN])  return 4;
    if (b[BUTTON_DOWN] && b[BUTTON_LEFT])   return 6;
    if (b[BUTTON_LEFT] && b[BUTTON_UP])     return 8;
    if (b[BUTTON_UP])    return 1;
    if (b[BUTTON_RIGHT]) return 3;
    if (b[BUTTON_DOWN])  return 5;
    if (b[BUTTON_LEFT])  return 7;
    return 0;
}

int8_t NESController::getXAxis(uint8_t player) const {
    if (player >= 2) return 0;
    return _buttonState[player][BUTTON_RIGHT] ? 127
         : (_buttonState[player][BUTTON_LEFT] ? -127 : 0);
}

int8_t NESController::getYAxis(uint8_t player) const {
    if (player >= 2) return 0;
    return _buttonState[player][BUTTON_DOWN] ? 127
         : (_buttonState[player][BUTTON_UP] ? -127 : 0);
}

bool NESController::allTrue(const bool a[], int n) {
    for (int i = 0; i < n; i++) if (!a[i]) return false;
    return true;
}

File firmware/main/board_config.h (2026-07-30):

// SPDX-License-Identifier: MIT
// Copyright 2026 Aaron Perkins

#pragma once
#include "driver/gpio.h"

// Pin map for the production PCB (see docs/HARDWARE.md). Constraint: NES LATCH/CLK/DATA must be
// RTC-capable so the ULP can poll the 4021 in deep sleep. LATCH/CLK need RTC OUTPUT-capable pins
// (25/26/27/32/33). DATA stays on 32/33 (they have internal pulls; GPIO34-39 are input-only with
// no pulls). Avoid strapping pins; never use GPIO12. Battery sense must be ADC1 (32-39); ADC2 is
// unusable while the radio is on.

// Reserved for programming (do not reuse): U0TXD=GPIO1, U0RXD=GPIO3, plus EN + IO0 (auto-reset).
// These route to the TC2030 Tag-Connect footprint (J4), pinned for the
// TC2030-FTDI-C232HD-DDHSP-0-DTR USB-UART cable (DTR drives IO0, RTS drives EN for esptool reset).
// Charging is via the barrel jack (J1, +5V) only, no onboard USB.

// NES Advantage serial interface (CD4021)
#define NES_LATCH       GPIO_NUM_25   // RTC, output
#define NES_CLK_P1      GPIO_NUM_26   // RTC, output
#define NES_CLK_P2      GPIO_NUM_27   // RTC, output
#define NES_DATA_P1     GPIO_NUM_32   // RTC, input + pull-up
#define NES_DATA_P2     GPIO_NUM_33   // RTC, input + pull-up

// Battery sense (resistor divider), ADC1
#define BATTERY_ADC_GPIO GPIO_NUM_34  // ADC1_CH6, input-only
#define BATT_EN          GPIO_NUM_13  // Q2 gate: drive HIGH to ground the divider while sampling,
                                      // LOW in deep sleep so the 1M/1M divider draws ~0

// Status LEDs (active-low)
#define LED_RED         GPIO_NUM_19
#define LED_GREEN       GPIO_NUM_21
#define LED_BLUE        GPIO_NUM_22

// Charger status pins (TP4056, open-drain active-low; R7/R8 pull them up to +3.3V on the board)
//
// CHG_STAT is the one pin that moved between board revisions: PCB 2.1 put it on an RTC-capable GPIO
// so the charger can wake the SoC out of deep sleep, which GPIO23 cannot do. Both candidates are
// listed here and the wired one is resolved at runtime, so a single build runs on either board.
// Use board::chg_stat_gpio(), never these constants directly.
#define CHG_STAT_REV20  GPIO_NUM_23   // charging, PCB 2.0: not RTC-capable, so no charger wake
#define CHG_STAT_REV21  GPIO_NUM_4    // charging, PCB 2.1: RTC, ext1 wakes on charger insert
#define STBY_STAT       GPIO_NUM_18   // standby / full, both revisions

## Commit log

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2026-07-13 firmware: real battery monitor + bench console
    Replace the battery stub with an ADC1 oneshot + line-fit cali reader: BATT_EN
    ground-switched 1M/1M divider on GPIO34 with a 300 ms settle for the ~50 ms C8 RC,
    EMA-smoothed coarse 1S-LiPo SoC, and live TP4056 CHG/STBY status. Calibrated on the
    2.0 board against a bench reference (BATT_CAL_PERMILLE=987, within +-13 mV 3.4-4.2 V).
    Add an esp_console UART REPL (console.cpp) for bench and automated testing, driven via
    serial_proxy.py send: batt, adc, led, get, profile, dirmode, transport, forget, sleep,
    autosleep, reboot, heap. App-side hooks in app_control.hpp (sleep/led-auto/profile/
    dirmode getters+setters).
    [app_main.cpp, battery.cpp, console.cpp]
2026-07-13 firmware: correct battery SoC while charging
    The divider senses at +BATT (cell terminal), so during charge the reading is
    elevated by the charge-current IR drop (measured ~70 mV at full Ichg on the 2.0
    board). Subtract BATT_CHARGE_OFFSET_MV (55 mV) before the SoC curve while
    is_charging(), and cap the reported SoC at 99% until STBY (is_full) confirms full,
    so it no longer reports a false 100% mid-charge. Verified: holds 99% through the
    charge, flips to 100% only on STBY.
    [battery.cpp]
2026-07-14 firmware: cut active draw ~20-65% (CPU 80 MHz, BLE modem sleep + slave latency)
    Bench-measured on PCB 2.0 (DPS-150 at the battery port, 3.7 V):
    - CPU 240 -> 80 MHz: -23 mA in every state, no radio-timing change; the
    4021 read grows ~0.13 -> ~0.4 ms inside the unchanged 2 ms poll loop.
    - BT modem sleep compiled in (ORIG, main-XTAL LPCLK). Classic disables it
    at init: the Switch handshake never sees it and the QoS-pinned active
    ACL gets nothing from it anyway. BLE runs with it enabled.
    - BLE conn update now requests slave latency 4 with the pinned 7.5 ms
    interval: the radio skips idle listens (with modem sleep, connected
    draw ~94 -> ~41 mA at 80 MHz). Press latency unchanged - pendi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
2026-07-14 firmware: pair with 8BitDo USB Adapter 2 (Switch 2 bridge)
    The Adapter 2 mimics the console's reconnect role: it pairs at GAP
    level, opens only the HID control channel, and waits for the
    controller to open the interrupt channel like a real Pro Controller
    does. Stock Bluedroid waits for the host instead, and its btm MITM
    link-key upgrade re-authenticates the just-encrypted link, which the
    ESP32 controller's LMP encryption pause/resume does not survive (ACL
    TX freeze, occasional lc_task assert crash).
    - bt_pro.cpp: bounded device-initiated HID connect ("kick") after a
    3 s host grace window, armed on GAP auth, bonded boot, and
    disconnect; cancelled on connect. Also fixes reconnect after a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
    [console.cpp]
2026-07-14 firmware: BlueRetro over BT Classic + authentic Pro input modes
    BlueRetro pairs at GAP, runs SDP, then opens the HID channels itself
    ~3 s after auth - and its CTRL connect races SSP encryption. Three
    more Bluedroid defects broke that flow, all patched at build time in
    tools/patch_bluedroid_hid_intr.py:
    - btm channel security gate: a CTRL connect racing pairing was queued,
    re-authenticated redundantly, and timed out refused before the HID
    layer saw it. HID PSMs are now mode-4 level-0 services (exempt from
    channel gating, like SDP); SSP still secures the ACL itself.
    - half-open completion now refuses to full-initiate while the host's
    ACL is up (the host is mid-flow; racing it strands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
2026-07-14 config: live controller tester, battery + turbo meters, BLE console; NES redesign
    Firmware (bt_config): add three GATT characteristics: INPUT (live per-player
    button/select/turbo/battery frame), LOG (device log tee via esp_log_set_vprintf),
    and CONSOLE (command line whose output streams back over LOG). Bring up the
    battery monitor in config mode so the meter reads a real cell, and poll the
    controller fast to measure turbo firing rate from A/B edges. Add a `config`
    bench-console command (app::enter_config_mode) to arm config mode over serial
    without the button gesture.
    Web: rewrite as a single self-contained index.html (app.js folded in) with a
    grey-and-red front-loader NES look: live button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
    [app_main.cpp, bt_config.cpp, console.cpp]
2026-07-15 firmware: distinct BLE address, correct QoS peer, cross-transport forget
    Three fixes from the power-tuning bench fix-list (verified on PCB 2.0):
    - #5 BLE gets its own static-random address (esp_ble_gap_set_rand_addr +
    own_addr_type RANDOM), derived in settings::ble_static_rand_addr from the
    factory MAC + identity gen with the two MSBs forced to 0b11. BR/EDR and BLE
    no longer share the chip BT MAC, so a dual-mode host that paired us over
    Classic first still enumerates the LE HID instead of folding it into the
    classic device record. Verified: distinct clean host records (public BR/EDR
    vs random BLE).
    - #2 Capture the QoS peer from ESP_BT_GAP_ACL_CONN_CMPL_STAT_EVT (fires for
    bo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
    [bt_transport.hpp]
2026-07-15 Public-release cleanup; detect disconnected controller and enter config mode
    Docs:
    - Concise pass; remove war stories and AI tells; new hero + 9 install
    photos (drop main.jpg); battery life in the feature list; 8BitDo USB
    Wireless Adapter 2 for Switch 2 (drop Adapter 1); drop hardware
    design-rationale sections (build/tweak reference only).
    - Firmware comments: drop dated bench notes and internal fix-list markers.
    Firmware:
    - A disconnected NES Advantage reads as all-buttons-held (both CD4021
    data lines idle-high), which oscillated player-select and tripped the
    Select+Start transport gesture into a reboot loop. Detect this at boot
    (NESController::diagnose) and enter BLE config/OT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
    [app_main.cpp, battery.cpp, bt_config.cpp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]
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2026-07-16 Add wiring-alarm troubleshooting (dirty select switch, back plate short) to config page + INSTALL
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2026-07-16 Replace Bluedroid Classic transport with a BTstack Switch Pro implementation
    The Switch 2 pages a Bluedroid device with the right CoD, completes the
    ACL, then drops it (HCI reason 0x05) before ever starting SSP. Neither
    advertising Secure Connections host support nor suppressing pre-auth L2CAP
    chatter unblocked it (both verified on-air); the remaining gate is host
    behavior we cannot see or reach from the application. BTstack replaces the
    whole Classic host, and its defaults already match what a real Pro does:
    silent on the ACL data plane until authenticated, SC host support
    advertised, no slave-initiated sniff.
    - components/btstack: pinned v1.8.2 subset + our Classic-only config; the
    vend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
2026-07-16 Fix six bugs found reviewing the BTstack transport before first flash
    Two adversarial reviews against the vendored BTstack source, since none of
    this has run on hardware yet:
    - Fresh pair never armed the reconnect kick, and s_peer was never seeded
    from pairing. A host that pairs and then waits for the controller to open
    HID (8BitDo Adapter 2, BlueRetro) hung until a power cycle. The old
    transport armed on GAP AUTH_CMPL; port that to SIMPLE_PAIRING_COMPLETE,
    and take the authoritative peer from CONNECTION_COMPLETE so a resume with
    two bonds stored cannot page the wrong host.
    - The kick retried every 5s against a ~15.4s page timeout.
    hid_device_connect() has no in-progress guard,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
2026-07-16 Init the controller Classic-only so esp_bt_controller_enable succeeds
    First flash: the controller initialized but enable failed, so BTstack never
    reached HCI_STATE_WORKING and the board never hit the air. The vendored
    transport inits with BT_CONTROLLER_INIT_CONFIG_DEFAULT, whose mode comes
    from CONFIG_BTDM_CTRL_MODE_BTDM (dual-mode, which the BLE boots need), then
    enabled Classic-only - and esp_bt_controller_enable requires the same mode
    the controller was initialized with. The old Bluedroid transport set
    bt_cfg.mode before init; the port kept the enable and dropped the init half.
    Phase A now passes: BTstack comes up at the rotated MAC, inquiry shows
    class 0x002508 and name 'Pro Controller'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
2026-07-16 Drop bogus HCI host flow control, keep Secure Connections on
    Two corrections to the BTstack transport found while bench-testing it against
    the Switch 2 for the first time.
    btstack_config.h enabled ENABLE_HCI_CONTROLLER_TO_HOST_FLOW_CONTROL, commented
    as "required for the ESP32 VHCI transport". It is not: the controller declares
    both commands unsupported (Read_Local_Supported_Commands octet 10 = 0xFC, bits 0
    and 1 clear) and refuses Host_Buffer_Size on the wire with status 0x11 at any
    parameters, while stubbing Set_Controller_To_Host_Flow_Control out as success.
    BTstack ignored the refusal, believed flow control was live, and answered every
    inbound ACL packet with a Host_Number_Of_Completed_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
2026-07-16 Switch 2 pairs directly; correct the docs that said it could not
    Direct Switch 2 pairing works from Change Grip/Order: SSP completes, HID opens
    both host-initiated and device-initiated, input reports stream at 66 Hz and the
    console sends rumble back. No dongle and no Nintendo-signed certificate.
    Two things were load-bearing. The CoD 0x002508 discovery gate, set before
    inquiry scan is enabled, which was already fixed - documented properly here for
    the first time, including the two ordering traps that make it hard to reach on
    an ESP32. And a console power cycle: a Switch 2 wedges into a state where it
    refuses SSP with every device, pages you, completes the ACL, then detaches with
    Authenticati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
2026-07-16 Drop 8BitDo USB Adapter 2 support notes and trim comments to constraints
    The Adapter 2 existed in these docs as the Switch 2 workaround. The stick pairs
    with a Switch 2 directly, so it is not a supported host and not worth designing
    around. Removed from the manual, the protocol reference, and the firmware
    comments. The 8BitDo Retro Receiver is unaffected and stays: it is a different
    product and a primary host.
    Comments and docs trimmed to the constraint, per AGENTS.md: no investigation
    narrative, no dates, no on-air-verification anecdotes. What survives is what the
    code cannot show - the CoD ordering traps, why host flow control must stay off,
    why the HID channels sit at security LEVEL_0 an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
2026-07-16 Document that a release must not erase NVS without a schema break
    The v2.1.0 full-flash asset erases settings and pairings, because nvs sits at
    0x9000..0xF000 and a raw merged image is one contiguous blob from 0x0 that pads
    the hole with 0xFF. Correct for a blank board, wrong for anything else, and the
    opposite of what partitions.csv says it wants ('nvs keeps its original
    offset/size, so existing bonds + settings survive').
    Records the constraint and the two ways to honour it: merge_bin --format hex,
    whose Intel HEX output preserves the gap, or keep the raw merged image strictly
    for blank boards and say so in the release notes. Erasing on a genuine NVS schema
    break is fine, deliberately and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
2026-07-16 Separate the update and blank-board flashing rules
    Updating an existing controller is the common case and must never erase NVS
    unless the release breaks the NVS schema: that is the OTA image, or the four
    separate images over serial, both of which skip the nvs hole at 0x9000..0xF000.
    Flashing a blank or bricked board is the raw merged image at 0x0, which pads that
    hole with 0xFF and erases NVS. That is correct and wanted there - nothing to
    preserve, and it is the recovery path for corrupt NVS. It stays supported; the
    release notes just have to label it so nobody reaches for it to update.
    Supersedes the blanket 'a release must not erase NVS' wording, which called the
    blank-board image a bug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
2026-07-17 Bump firmware to 2.2.0
    Adds Select-held chords for Home, ZL+ZR, ZL, ZR, and Capture, so the version in
    the config web app distinguishes a build that can reach the Switch's own buttons
    from one that cannot. Backward compatible: every existing mapping is unchanged
    except Minus, which now fires on Select release instead of press.
    Also fixes a drift this bump would otherwise repeat. The version lives in two
    places: FW_VERSION here (config GATT -> web app) and version.txt (ESP-IDF
    PROJECT_VER -> app descriptor, which is what OTA tooling reads). Nothing greps
    version.txt, CMake reads it implicitly, and it is captured at configure time --
    so v2.1.0 bumped only FW_VERSION and shipped an app descrip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
    [bt_config.cpp]
2026-07-17 Don't let the first BLE OTA attempt drop the link; mark config mode with green
    Two config-mode fixes.
    esp_ota_begin() was passed the image size, which makes it erase the whole target
    slot before returning. On a slot still holding the previous firmware that is
    ~766 ms of solid flash work, and the BLE link does not survive it: the radio is
    starved, the central's supervision timer expires, and the erase then completes
    and notifies READY into a connection that is already gone (reason 0x8). Users saw
    "the first update always fails, the second works" -- the dead attempt still left
    the slot blank, so the retry erased in ~159 ms and slipped under the timeout.
    BlueZ's 720 ms default is what bites (m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
    [bt_config.cpp]
2026-07-17 Bump firmware to 2.2.1
    Fixes the first BLE OTA attempt dropping the link, and marks config mode with a
    green blink. No gameplay change from 2.2.0.
    Note for anyone updating from 2.2.0 or earlier on a Linux host: the fix only
    takes effect once 2.2.1 is running, so the update *to* it still hits the old bug
    once. Retry and it lands.
    [bt_config.cpp]
2026-07-27 Bound the Select chord window, and keep BLE out of it entirely
    Select could not be held. Minus was withheld for the whole press and pulsed on
    release, so a game wanting Minus down for as long as the button is down could
    never get it, and a Windows joystick tester showed Select firing on release.
    Reported by a customer on BLE, where the feature buys nothing at all.
    Minus still cannot be sent on press: HID has no undo, so putting minus=1 on the
    wire and retracting it when the chord arrives leaves the host having already
    opened the menu. What was wrong was withholding it *indefinitely*. The wait is
    now bounded. A chord must start inside the window; once it closes with no chord,
    Minus commits a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
    [app_main.cpp, bt_config.cpp]
2026-07-27 Add host-side tests for the chord layer
    The chord state machine has timing edges that are miserable to find on hardware
    and cheap to check off it. Writing these caught a real bug before it shipped:
    the window close was gated on no member being currently down, so a button
    pressed after the deadline blocked the commit and then chorded anyway, defeating
    the point of bounding the window.
    apply_chords() is static and sits behind ESP-IDF, so run.sh lifts the chord
    section out of app_main.cpp and compiles it against stubs and a fake clock. The
    tests therefore run the shipped code rather than a transcription that drifts.
    Extraction keys on the section's banner comments, not line numbers, and fails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
    [chords_test.cpp]
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2026-07-27 Refuse an OTA image the device would reject, before sending it
    Dropping the blank-board image on the OTA card uploaded 1012 KB over BLE and
    then failed with ESP_ERR_OTA_VALIDATE_FAILED, which says nothing about what to
    do instead. The two release assets sit next to each other and their names do not
    say which is which, so picking the wrong one is easy.
    The check is the same one esp_ota_write makes: 0xE9 at byte 0 and
    esp_app_desc_t's magic at 0x20. A merged flash image is padded from 0x0, so it
    opens with 0xFF where the bootloader hole is, which is worth naming explicitly
    rather than reporting as a generic bad image.
2026-07-27 Stop an INFO frame from discarding a setting you just picked
    Choosing a different Select chords window did not stick: Apply wrote back the
    old value. The device republishes INFO on its own, on a console command or when
    the controller-wiring status changes, and onInfo rebuilt every settings select
    from device state. An INFO frame between picking a value and pressing Apply
    reverted the pick silently, and Apply then sent what the device already had.
    Rebuilding the option list also drops the click in progress when the dropdown is
    open, which is the likelier way to hit this: the list is rewritten under the
    open menu. So options are now swapped only when they actually differ, and a
    control the us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
2026-07-29 Drop the Switch/Receiver button profile that swapped A and B
    Profile 2 ("NSO NES") sent NES A as Pro B and NES B as Pro Y, on the theory that
    Switch Online's NES emulator wants the SNES-style diamond pair. It does not: NSO
    reads Pro A/B as NES A/B (Pro X is a second NES B), so the profile the manual
    recommended for NES games delivered them swapped. The 8BitDo Retro Receiver is
    fine with the literal mapping too, so nothing wanted the remap.
    Classic keeps one profile, "Literal", and loses the table behind it. A stored
    profile=1 clamps back to it on boot (app_main), and the config page disables a
    picker with only one entry rather than showing a menu of one.
    The only bench evidence for profile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
2026-07-29 Bump firmware to 2.4.0
    2.3.0 shipped and was tagged, so both version strings were stale for the three
    changes now sitting on top of it: the OTA image guard, the INFO frame no longer
    discarding a setting you just picked, and dropping the A/B-swapping button
    profile. Minor rather than patch because that last one removes a setting.
    Clean rebuild done so version.txt reaches the app descriptor; the image now
    reports 2.4.0 in both places and nothing claims 2.3.0.
    [bt_config.cpp]
2026-07-29 Record why a link came up or didn't, and keep re-paging a bonded host
    A customer's Analogue Pocket dock will not auto-reconnect in Switch Pro mode - it
    has to be paired every session - and there is no Pocket here to test against. Two
    changes: instrument the reconnect path so a user can send back what happened, and
    fix the most likely cause on our side.
    linklog.cpp is a black box, not a debug mode. The interesting part of "it won't
    reconnect" happens at power-on, before a user could arm anything, and the gesture
    that reads it out is itself a reboot - so it always records, into an RTC_NOINIT
    ring that survives esp_restart and deep sleep, plus an 8-boot NVS summary for the
    power-off case. It c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
    [app_main.cpp, bt_config.cpp, console.cpp]
2026-07-29 Record the host's half of a pairing attempt, not just ours
    The log answered "why did the reconnect fail" but had nothing for "this adapter
    refuses to pair", where the deciding facts all belong to the host: that it paged
    us at all, its class of device, its IO capability, and what it demands. Record
    the connection request with the peer's class of device, the role change, the IO
    capability request and response with authentication requirements and OOB flag,
    numeric confirmation, passkey and OOB requests, and decode the simple-pairing
    status.
    The dump spells out what each combination means for a device that is
    NoInputNoOutput with no display and no spare keys: a passkey or OOB request
    cannot be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
2026-07-29 Record the BLE pairing handshake too
    The recorder only ever ran on the Classic transport, so a BLE-mode log came back
    with one useful line: the boot marker saying transport=ble. Everything a refused
    BLE pairing turns on was either never recorded or thrown away, including the
    authentication result, which bt_ble.cpp reduced to a bool and printed.
    Recorded now: bond count at boot, whether advertising started, the HID connect,
    which keys the host distributed, the authentication result with Bluedroid's
    failure reason and auth mode, the granted connection parameters, and the
    disconnect reason. Passkey, numeric-comparison and OOB requests get their own
    handlers, which did not exist at all; with ES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
2026-07-31 Release 2.4.1
    Bump FW_VERSION and version.txt together, and rebuild clean so the app
    descriptor picks the new PROJECT_VER up at configure time. Verified in the
    binary: the only version-shaped strings are 2.4.1 and the IDF's own 6.0.1, and
    esp_app_desc reads 2.4.1.
    The 2.4.0 reference in web/index.html is deliberately left alone. It names the
    release that introduced the link log, so it answers "is this device new enough",
    and moving it with every bump would tell a 2.4.0 device to update for a feature
    it already has.
    docs/FIRMWARE.md gains the board.{hpp,cpp} row the module table was missing.
    [bt_config.cpp]
2026-07-31 Drop the 22 uF bulk caps from 25 V to 16 V
    C1, C4, C5, C6, C7 and C9 move from Samsung CL21A226MAQNNNE (25 V, LCSC C45783)
    to CL21A226KOQNNNE (16 V, +/-10%, LCSC C296720). Same case, same value, tighter
    tolerance, and a lot cheaper.
    The 25 V rating was never needed. The highest rail any of these sit on is the
    +5 V TP4056 input, and 16 V still leaves more headroom than the 10 V parts the
    PCB 2.0 build shipped and validated with. What 25 V did buy was cost: it is a
    premium high-volumetric-efficiency MLCC, and at the 120 pieces a 20 board run
    needs it was the second most expensive line on the board after the ESP32 module.
    PCBWay quoted $75 for the six-per-board line; JLCPCB charges $40.38.
    C4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
    [bt-nes-advantage-pcb.kicad_pcb, bt-nes-advantage-pcb.kicad_sch]
2026-07-31 Authenticate a reconnect we page, like a real Pro Controller does
    A bonded controller that pages its host and then opens HID in the clear is
    asking a Security Mode 4 host to break the link: Core 5.2 Vol 3 Part C 5.2.2.2
    says a device that receives an L2CAP request for a non-SDP service, on an
    unencrypted link where both sides support SSP, shall disconnect with 0x05
    Authentication Failure. BTstack enforces exactly that on its own incoming
    channels in l2cap_handle_remote_supported_features_received. We were the device
    handing over that unencrypted channel.
    The flat gap_set_security_level(LEVEL_0) is what got us there. Dropping the
    requirement was right - it stopped our own stack refusing our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
2026-07-31 Release 2.4.2
    binary: the only version-shaped strings are 2.4.2 and the IDF's own 6.0.1, and
    esp_app_desc reads 2.4.2.
    Carries the reconnect authentication fix. Hosts that require an encrypted link
    and expect the controller to initiate one - the Analogue Pocket dock is the
    known case - could never reconnect on a stored bond before this.
    The 2.4.0 reference in web/index.html is deliberately left alone, for the same
    reason as in 2.4.1: it names the release that introduced the link log.
    Also ignore firmware/dist/, where the release images are built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
    [bt_config.cpp]
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2026-08-01 Release 2.5.0
    binary: the only version-shaped strings are 2.5.0 and the IDF's own 6.0.1, and
    esp_app_desc reads 2.5.0.
    Minor, not patch: Classic gains a second button profile and every profile on
    both transports is renamed to state its own mapping, so the picker a user sees
    and the names in the config page change.
    Carries the reconnect authentication fix that 2.4.2 was built for. 2.4.2 itself
    was never tagged or published - it went straight to the customer whose Analogue
    Pocket dock found the bug, and this supersedes it. Nothing should ship as 2.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
    [bt_config.cpp]
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
